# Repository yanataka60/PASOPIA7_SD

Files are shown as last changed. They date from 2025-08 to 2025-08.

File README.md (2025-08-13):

# TOSHIBA PASOPIA7、PASOPIAにSD-Cardとのロード、セーブ機能

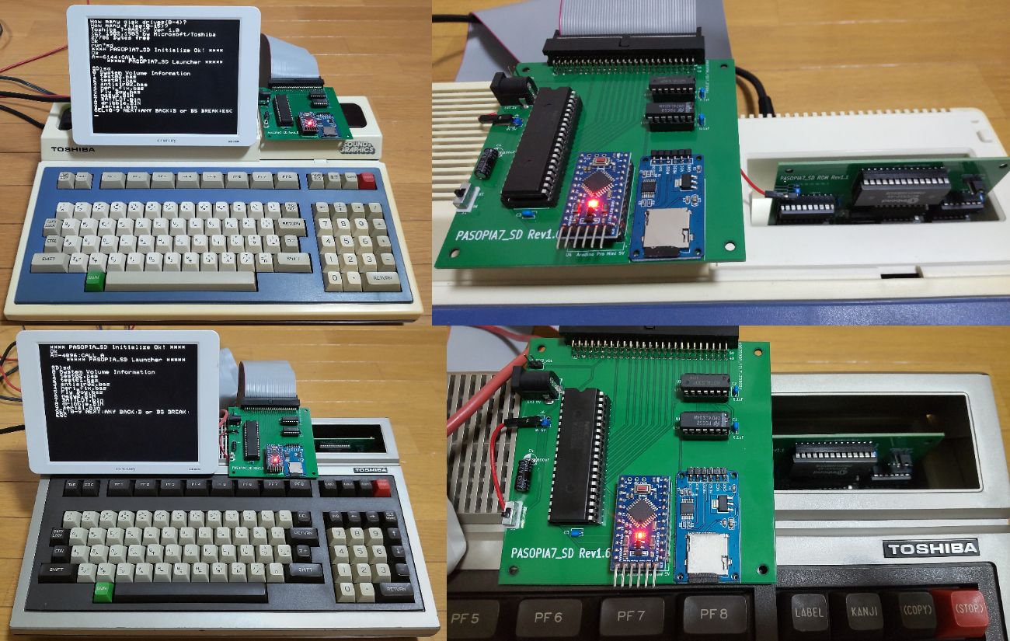
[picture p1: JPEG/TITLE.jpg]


　TOSHIBA PASOPIA7、PASOPIA(T-BASIC Ver1.1)でCMTの代わりにSD-CARDからロード、セーブを実現するものです。

　SDから読み込めるCMTのファイル形式はEMUで一般的なWAV、CASには対応していません。bugfire2009さんのDumpListEditorを使ってバイナリ形式に変換したものを使います。

　機械語 -> 各モデル固有ヘッダ付きBINファイル、拡張子は.bin

　BASIC -> BASファイル、拡張子は.bas

　CMTからの読み込み実行に数分掛かっていたゲームも数十秒で実行できます。

　ただし、CMT用プログラムのすべてがSD対応となるわけではありません。特に市販ゲームはCMT読み込みに独自ルーチンを使っているものもあるため、SD対応は不明です。

　なお、Arduino、ROMへ書き込むための機器が別途必要となります。

#### 　PASOPIAは、T-BASIC Ver1.1のみの対応です。また、OA-BASICも未対応です。

## 重要!!
　PASOPIA、PASOPIA7においてあるあるの電源ユニット部フィルムコンデンサの破裂ですが、修理に適切な品への交換されていない場合、電源電圧は正常(+5V)なのに信号電圧が異常(+10V程度)な状態となることがあるようです。

　私は当初電源電圧が正常であることを確認したものの原因が判らずArduino及びUSBシリアル変換モジュールを数個破壊してしまいました。

　当方ではCZRD信号の電圧が異常だったため、念のためPASOPIA7_SD基板にCZRD信号電圧を測るための「J6 TEST_VOL」端子を設けてあります。

　ICを装着する前に電圧をチェックし、+5V以上の電圧が出ているようであればまず電源ユニット部フィルムコンデンサを適切な品に交換してください。

　また、事前に調査するのであればPAC SLOT2 15Pin(CRD)の電圧を測ってみてください。

## 回路図(PASOPIA7、PASOPIA共通)
　PASOPIA7_SD本体基板とPASOPIA7_SD_ROM基板に分かれています。

　SDアクセスルーチンを読み込むためにPASOPIA7_SD_ROM基板(読込専用RAMPAC)を使用します。

　XPAC2又はRAMPACを持っていればそれにCMTから読み込んだSDアクセスルーチンを保存しておくことで使用することも可能です。詳細は後述の「XPAC2又はRAMPACの使用」を参照してください。

### PASOPIA7_SD本体基板
　KiCadフォルダ内のPASOPIA7_SD.PDFを参照してください。

[回路図](https://github.com/yanataka60/PASOPIA7_SD/blob/main/Kicad/1.6/PASOPIA7_SD.pdf)

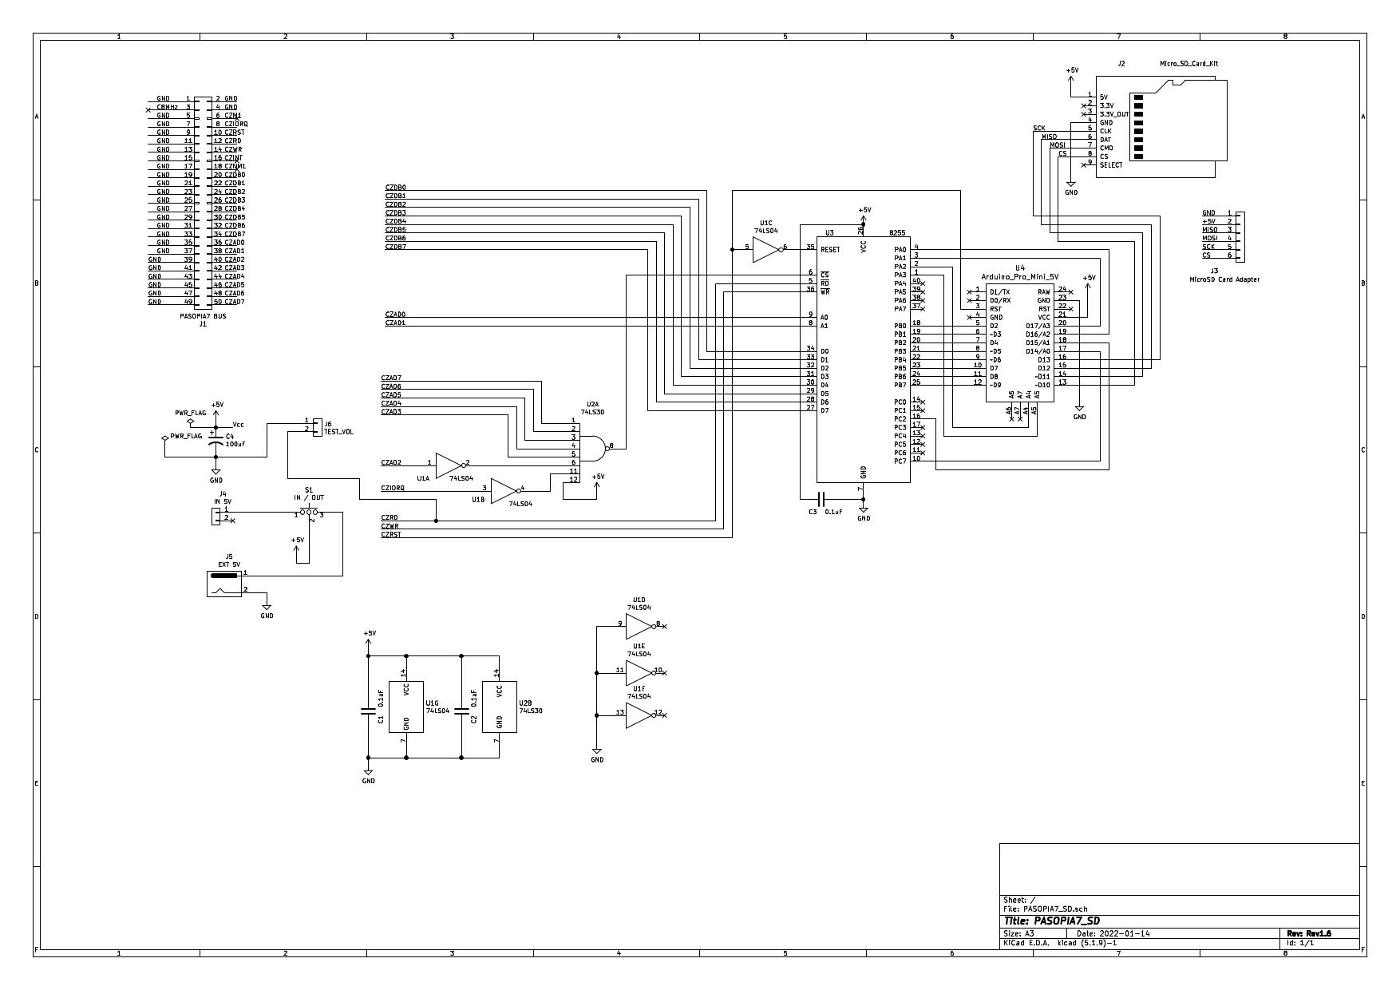
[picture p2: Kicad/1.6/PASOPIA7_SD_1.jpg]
PASOPIA7_SD


## 部品
|番号|品名|数量|備考|
| --- | --- | --- | --- |
|J1|2x25ボックスヘッダ|1|共立エレショップ JS-1200R-50など、秋月電子通商 PH-2x40RGなどのピンヘッダでも代用可(注4)|
||J2,J3のいずれか|||
|J2|Micro_SD_Card_Kit|1|秋月電子通商 AE-microSD-LLCNV (注1)|
|J3|MicroSD Card Adapter|1|Arduino等に使われる5V電源に対応したもの(注2)|
|U1|74LS04|1||
|U2|74LS30|1||
|U3|8255|1||
|U4|Arduino_Pro_Mini_5V|1|Atmega328版を使用 168版は不可。(注3)|
|C1-C3|積層セラミックコンデンサ 0.1uF|3||
|C4|電解コンデンサ 16v100uF|1||
|S1|3Pスライドスイッチ|1|秋月電子通商 SS12D01G4など|
|J4|コネクタ 2Pin|1|ピンヘッダで代用するときはGNDと間違えないよう1Pinで5Vだけにしたほうが良い|
|J5|DCジャック|1|秋月電子通商 MJ-179PHなど|
|J6|2P ピンヘッダ|1|秋月電子通商 PH-1x40SGなど|
||2.54mmピッチ2x25Pinフラットケーブル|1||
||PASOPIA7_SDとPASOPIA7_SD_ROMを繋ぐケーブル|15cm～30cm|ジャンプワイヤー メス-メスなど|

PASOPIA7_SDに外部から電源を供給する場合
|番号|品名|数量|備考|
| --- | --- | --- | --- |
||ACアダプター 5V|1|秋月電子通商 M050200-A010JPなど|

### 注1)秋月電子通商　AE-microSD-LLCNVのJ1ジャンパはショートしてください。

### 注2)MicroSD Card Adapterを使う場合

J3に取り付けます。

MicroSD Card Adapterについているピンヘッダを除去してハンダ付けするのが一番確実ですが、J2の穴にMicroSD Card Adapterをぴったりと押しつけ、裏から多めにハンダを流し込むことでハンダ付けをする方法もあります。なお、この方法の時にはしっかりハンダ付けが出来たかテスターで導通を確認しておいた方が安心です。

ハンダ付けに自信のない方はJ1の秋月電子通商　AE-microSD-LLCNVをお使いください。AE-microSD-LLCNVならパワーLED、アクセスLEDが付いています。

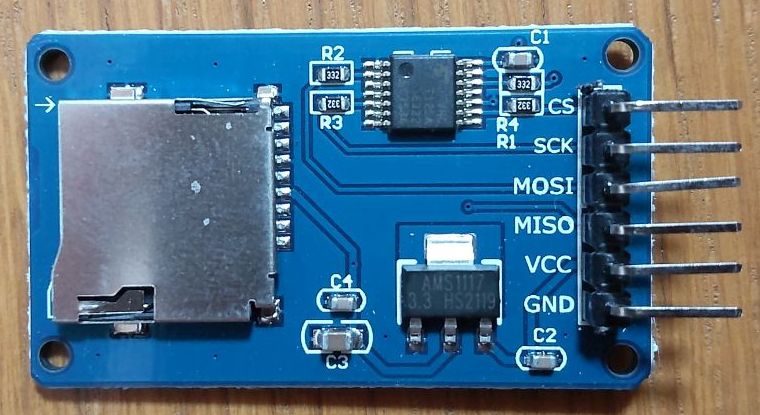
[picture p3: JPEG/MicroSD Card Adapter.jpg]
MicroSD Card Adapter1


### 注3)Arduino Pro MiniはA4、A5ピンも使っています。

#### 注4)ピンヘッダで代用するときは、基板から若干浮かせてピンヘッダをハンダ付けするとフラットケーブルをスムーズに抜き差しできます。

### PASOPIA7_SD_ROM基板
　KiCadフォルダ内のPASOPIA7_SD.PDFを参照してください。

[回路図](https://github.com/yanataka60/PASOPIA7_SD/blob/main/Kicad/ROM/PASOPIA7_SD_ROM.pdf)

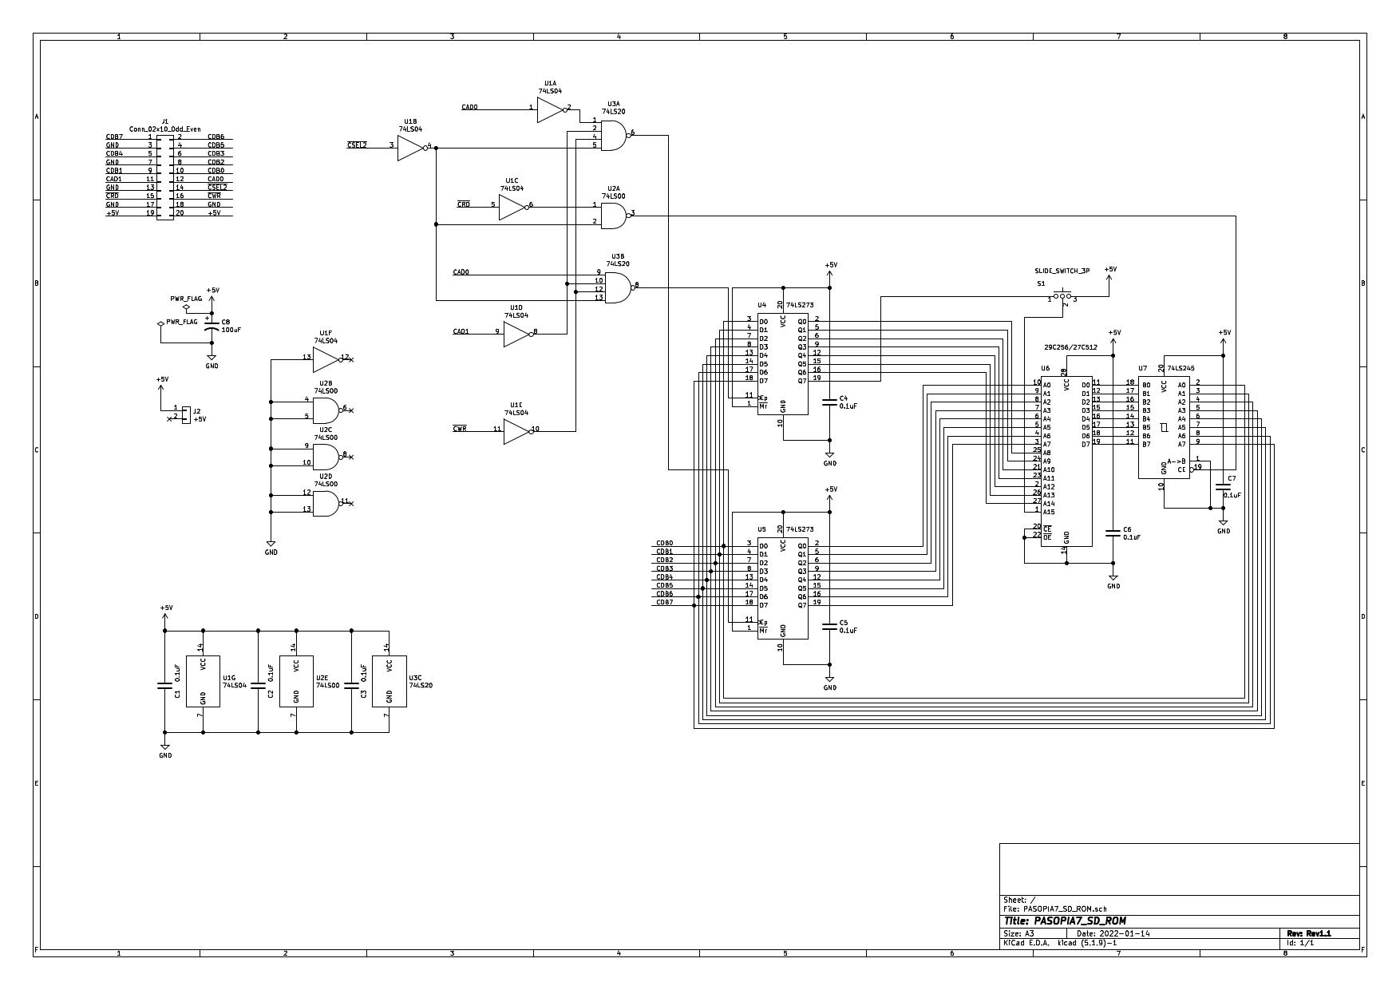
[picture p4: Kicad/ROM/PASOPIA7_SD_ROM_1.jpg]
PASOPIA7_SD

|番号|品名|数量|備考|
| --- | --- | --- | --- |
|U1|74LS04|1||
|U2|74LS00|1||
|U3|74LS20|1||
|U4-U5|74LS273|2||
|U6|ROM 27256/29C256又は27512/27C512相当品|1|入手しやすいものでOK、28C256は不可|
|U7|74LS245|1||
|C1-C7|積層セラミックコンデンサ 0.1uF|7||
|C8|電解コンデンサ 16v100uF|1||
|S1|3Pin ピンヘッダーとジャンパーピン又は3Pスライドスイッチ|1|秋月電子通商 SS12D01G4など|
|J2|コネクタ 2Pin|1|ピンヘッダで代用するときはGNDと間違えないよう1Pinで5Vだけにしたほうが良い|

## 取り付け(PASOPIA7、PASOPIA共通)
　PASOPIA7_SD本体基板はPASOPIA7(PASOPIA)本体後部の拡張端子とフラットケーブルで接続します。50Pinフラットケーブルは、コネクタのボッチとケーブルの返しが両方上になる側のコネクタを本体に嵌めます。

　ケーブルの返しを下にして本体に嵌めると一見嵌っているように見えても接触不良を起こしていることがあります。

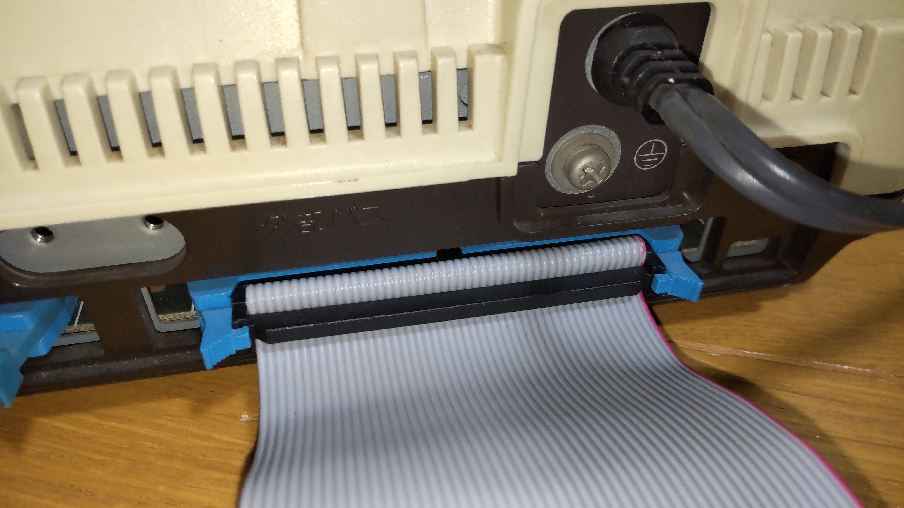
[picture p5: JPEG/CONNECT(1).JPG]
Connect1


　PASOPIA7_SD_ROM基板はPACスロット2に挿入します。この時PASOPIA7_SD_ROM基板は部品実装面を手前にして挿入してください。基板の右端をスロットの右に合わせるように挿入すればズレずに挿入できると思います。

　次にPASOPIA7_SD_ROM基板への+5V供給のため、PASOPIA7_SD_ROM基板の+5V端子(J2)とPASOPIA7_SD本体基板の+5V端子(J4)を繋いでください。

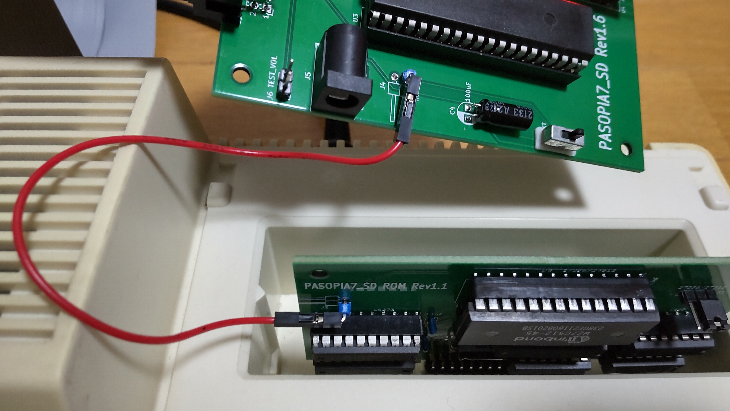
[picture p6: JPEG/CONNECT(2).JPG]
Connect2


　XPAC2又はRAMPACを使用するときは、外部電源として5V電源アダプタを接続するか、内部電源としてPAC SLOT1の43Pin又は44Pinから+5Vを取り出してジャンプワイヤー オス-メスなどで接続します。

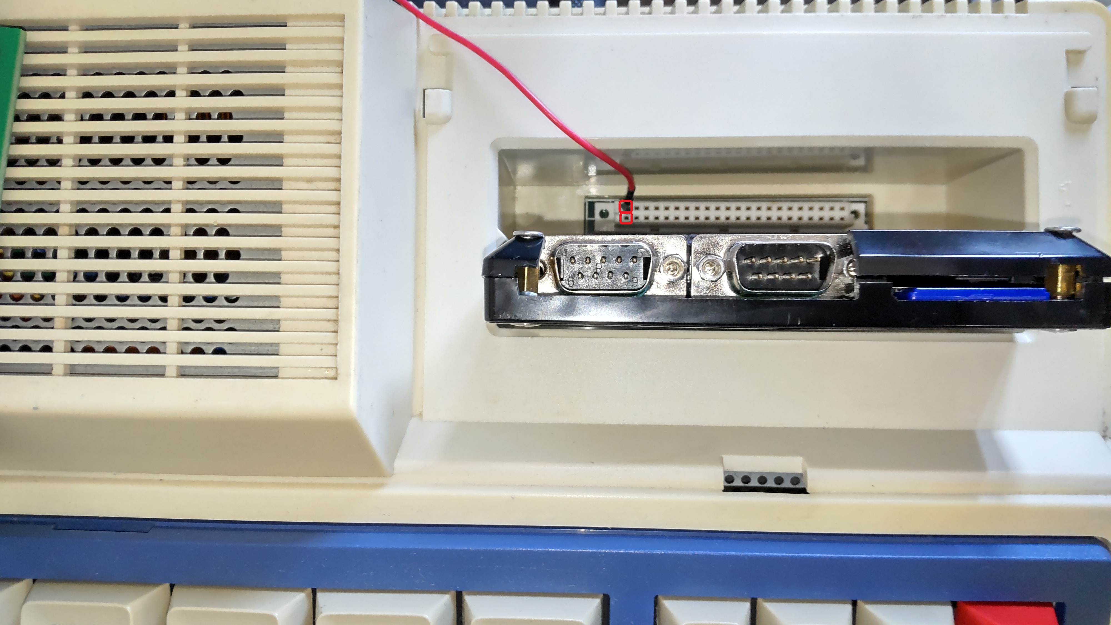
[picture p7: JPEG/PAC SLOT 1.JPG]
Connect3


## ROMへの書込み(PASOPIA7、PASOPIA共通)
　Z80フォルダ内のRAMPAC.binをROMライター(TL866II Plus等)を使って27256又は27512に書き込みます。

　実際に使用しているのは32KByte分(32Kx8)です。

　PASOPIA7_SD_ROM基板のROMはPASOPIA7(PASOPIA)からはRAMPACとして扱われます。(PASOPIA7(PASOPIA)から書き込みはできません。)

## RAMPAC.binに登録されているファイル
　RAMPAC.binに登録されているファイルは次の2つになります。

|ファイル名|種類|備考|
| --- | --- | --- |
|sd|BASIC|PASOPIA7用|
|SDBOOT|BINARY|PASOPIA7用|
|sdt|BASIC|PASOPIA用|
|SDTBOOT|BINARY|PASOPIA用|

　また、RAMPAC.binへのファイル登録はTAKEDAさんのEMU ePASOPIA7で行っており、RAMPAC1としてファイルを選択すればePASOPIA7から読み書き出来ます。

## XPAC2又はRAMPACの使用(PASOPIA7、PASOPIA共通)
　XPAC2又はRAMPACを持っていればPASOPIA7_SD_ROM基板の代わりに使用できます。

　ただし、PASOPIA7_SD本体基板への+5V供給を独自に用意する必要があります。内部から引き出すか、5V電源アダプタを用意するかですが、PACスロット1 44Pinから取るのが簡単だと思います。

### XPAC2
　ePASOPIA7で扱うRAMPACKが32KByteなのに対してXPAC2で扱うSLOT4は64KByteです。

　XPAC2のSD-CARDへRAMPAC.binをコピーしてXPAC2 SLOT4へ登録することも可能とは思われますが、容量が32KByteとなってしまう気がします。

　XPAC2 SLOT4を64KByteのまま使いたいのであればsd.wav(sdt.wav)、SDBOOT.wav(SDTBOOT.wav)をCMTインタフェースから読み込み、XPAC2 SLOT4へ保存してください。

### RAMPAC
　RAMPAC.binをRAMPACへ登録する方法がありませんのでsd.wav(sdt.wav)、SDBOOT.wav(SDTBOOT.wav)をCMTインタフェースから読み込み、RAMPACへ保存してください。

## Arduinoプログラム(PASOPIA7、PASOPIA共通)
　Arduino IDEを使ってArduinoフォルダのPASOPIA7_SDフォルダ内PASOPIA7_SD.inoを書き込みます。

　SdFatライブラリを使用しているのでArduino IDEメニューのライブラリの管理からライブラリマネージャを立ち上げて「SdFat」をインストールしてください。

　「SdFat」で検索すれば見つかります。「SdFat」と「SdFat - Adafruit Fork」が見つかりますが「SdFat」のほうを使っています。

注)Arduinoを基板に直付けしている場合、Arduinoプログラムを書き込むときは、PASOPIA7(PASOPIA)本体とは接続を外し、U1 74LS04を外したうえで書き込んでください。

## SD-CARD(PASOPIA7、PASOPIA共通)
　出来れば8GB以下のSDカードを用意してください。

　ArduinoのSdFatライブラリは、SD規格(最大2GB)、SDHC規格(2GB～32GB)に対応していますが、SDXC規格(32GB～2TB)には対応していません。

　また、SDHC規格のSDカードであっても32GB、16GBは相性により動作しないものがあるようです。

　FAT16又はFAT32が認識できます。NTFSは認識できません。

## 操作方法
### PASOPIA7
　起動直後に「RUN"sd"」を実行してSDアクセスルーチンの読込、初期化の実行を行います。

　SDアクセスルーチンはE800h～EFCFhに読み込まれます。

　SDアクセスメニューを表示するにはA=&HE800:CALL Aを実行しますが、PF6ファンクションキーに登録してありますのでPF6ファンクションキーを押しても大丈夫です。

### PASOPIA(T-BASIC Ver1.1のみ対応)
　起動直後に「RUN"sdt"」を実行してSDアクセスルーチンの読込、初期化の実行を行います。

　SDアクセスルーチンはF000h～F776hに読み込まれます。

　SDアクセスメニューを表示するにはA=&HF000:CALL Aを実行しますが、PF6ファンクションキーに登録してありますのでPF6ファンクションキーを押しても大丈夫です。

#### 扱えるファイル(PASOPIA7、PASOPIA共通)
bugfire2009さんのDumpListEditorを使ってバイナリ形式に変換したものを使います。

扱う機種をPASOPIA7に変更したうえで変換します。

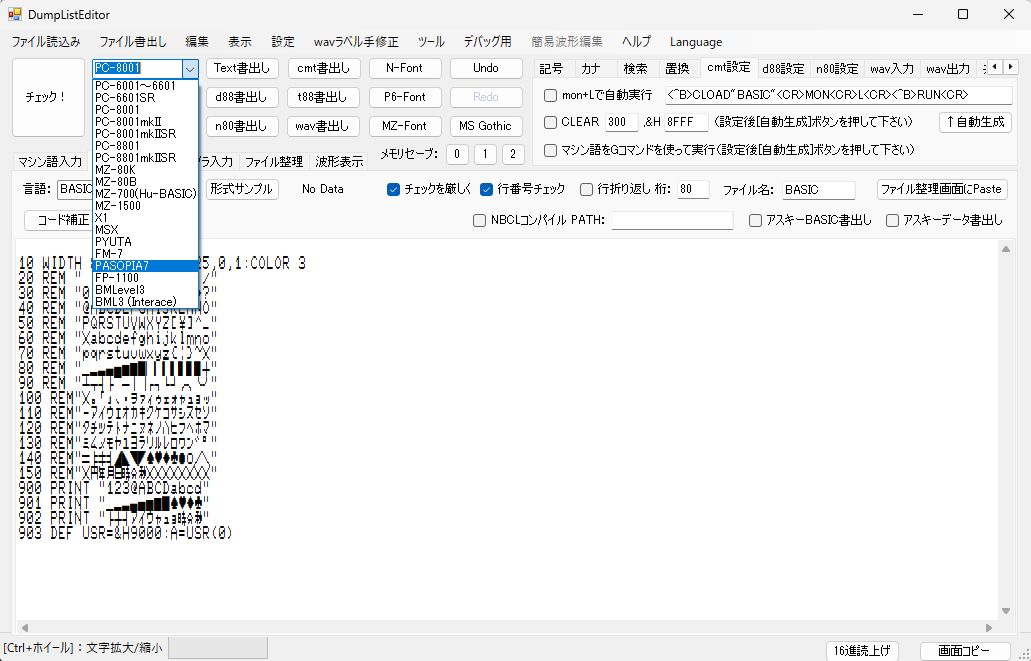
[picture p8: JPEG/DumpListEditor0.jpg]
DumpListEditor0


##### 機械語 -> 「BINファイル書出し(各モデル固有ヘッダ付き)」で保存、拡張子は.bin

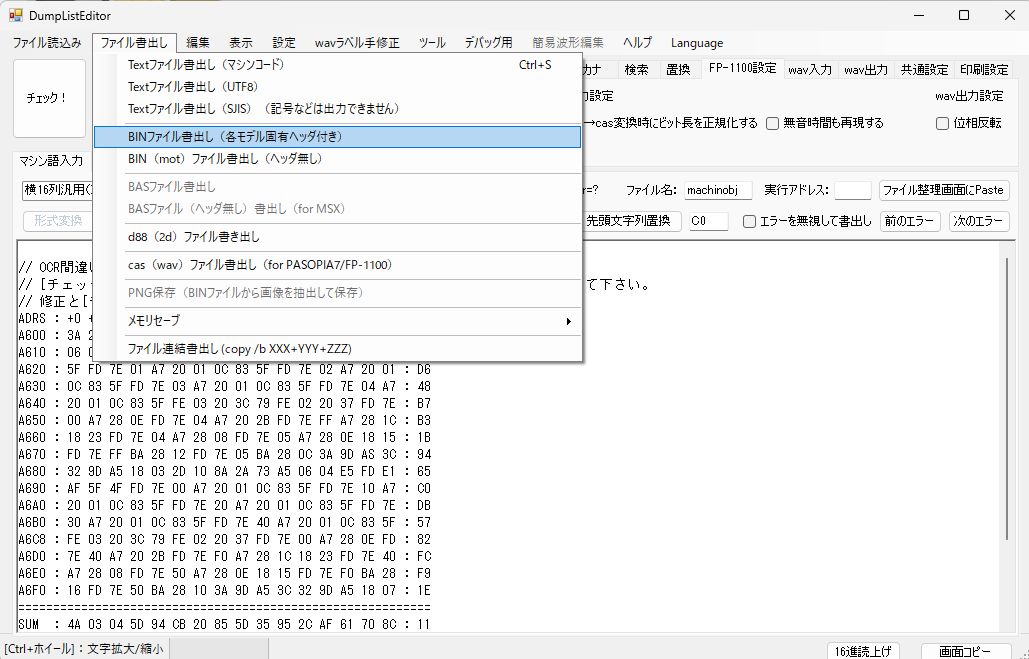
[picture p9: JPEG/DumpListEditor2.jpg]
DumpListEditor1


##### BASIC -> 「BASファイル書出し」で保存、拡張子は.bas

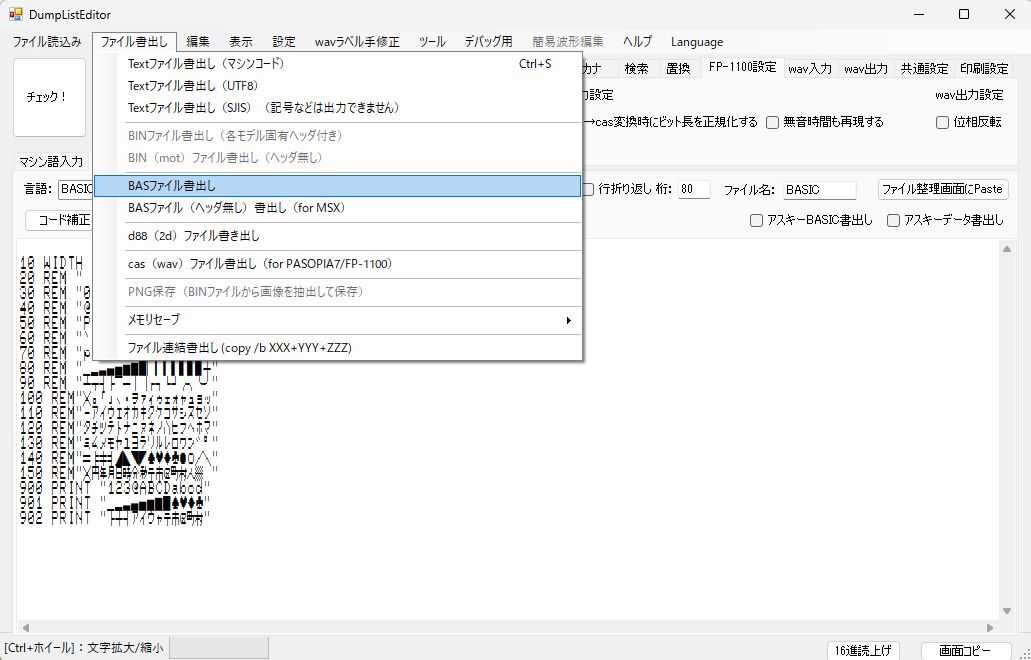
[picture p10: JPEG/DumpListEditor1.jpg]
DumpListEditor2


### コマンド(PASOPIA7、PASOPIA共通)
　コマンド入力時にBSキー又は左カーソルキーで直前に入力した文字を訂正できます。

　CLR、HOME、上・下・右カーソルキーは画面が乱れるだけで入力文字の訂正は出来ません。

#### SD[RETURN]又はSD 文字列[RETURN]
　文字列を入力せずにSD[RETURN]のみ入力するとSD-CARDルートディレクトリにあるファイルの一覧を表示します。

　文字列を付けて入力すればSD-CARDルートディレクトリにあるその文字列から始まるファイルの一覧を表示します。
　10件表示したところで指示待ちになるのでESCキーで終了、Bキー又はBSキーで前の10件に戻ります。それ以外のキーで次の10件を表示します。

　表示される順番は、登録順となりファイル名アルファベッド順などのソートした順で表示することはできません。

　LOADしたいファイルを見つけたら左端の数字のキーを押せばLOADされます。

　BASICプログラムか、機械語プログラムかは自動で判断します。

　なお、PASOPIA7はE7FFh以降、PASOPIAはEFFFH以降へ機械語プログラムがLOADされた場合、次の五段階の挙動となります。

||PASOPIA7|PASOPIA|挙動|
|---- | --- | --- | --- |
|1|～E8FCh|～F0FAh|機械語プログラムをLOAD後は、SM,SBコマンドが使用できなくなります。LM,LG,LB,SD,J,Q,Bコマンドは使用できます。|
|2|～EC54h|～F423h|機械語プログラムをLOAD後は、J,Q,Bのみ使えます。SD,LMコマンドでLOADした後、Jコマンドでの実行は可能です。|
|3|～EDC6h|～F582h|BASICプログラムLOADの限界です。通常はCLEAR文で設定したメインメモリの上限E800hですが、F000hに変更すればEDC6hまでのBASICプログラムを一度だけLOAD出来ます。|
|4|～EE61h|～F614h|BASIC中からはこれ以降への機械語LOADは出来ません。|
|5|～EEE7h|～F691h|機械語プログラムをLOAD後は、すべてのコマンドが使えません。EDC7h以降までLOADされた場合は強制的に実行番地にジャンプを試みます。|

##### 例)
　　SD[RETURN]

　　SD S[RETURN]

　　SD SP[RETURN]

#### LM DOSファイル名[RETURN]
　指定したDOSフィル名の機械語プログラムをSD-CARDからLOADします。

　拡張子が「bin」であるファイルだけが対象でファイル名の最後が「.BIN」でない場合には自動的に付加されます。

　なお、PASOPIA7はE7FFh以降、PASOPIAはEFFFH以降へ機械語プログラムがLOADされた場合、次の五段階の挙動となります。

||PASOPIA7|PASOPIA|挙動|
|---- | --- | --- | --- |
|1|～E8FCh|～F0FAh|機械語プログラムをLOAD後は、SM,SBコマンドが使用できなくなります。LM,LG,LB,SD,J,Q,Bコマンドは使用できます。|
|2|～EC54h|～F423h|機械語プログラムをLOAD後は、J,Q,Bのみ使えます。SD,LMコマンドでLOADした後、Jコマンドでの実行は可能です。|
|3|～EDC6h|～F582h|BASICプログラムLOADの限界です。通常はCLEAR文で設定したメインメモリの上限E800hですが、F000hに変更すればEDC6hまでのBASICプログラムを一度だけLOAD出来ます。|
|4|～EE61h|～F614h|BASIC中からはこれ以降への機械語LOADは出来ません。|
|5|～EEE7h|～F691h|機械語プログラムをLOAD後は、すべてのコマンドが使えません。EDC7h以降までLOADされた場合は強制的に実行番地にジャンプを試みます。|

##### 例)
　　LM TEST[RETURN] -> DOSファイル名「TEST.BIN」を読み込みます。

　　LM TEST.BIN[RETURN] -> DOSファイル名「TEST.BIN」を読み込みます。

　　LM TEST.BAS[RETURN] -> DOSファイル名「TEST.BAS.BIN」を読み込みます。

#### LG DOSファイル名[RETURN]
　指定したDOSフィル名の機械語プログラムをSD-CARDからLOADした後、実行開始アドレスへジャンプします。

　LOAD後そのまま実行するのでFF64hまでLOADしても大丈夫です。

　LOADした後、実行開始アドレスへジャンプする以外はLMコマンドと同じです。

#### LB DOSファイル名[RETURN]
　現在選択しているPROGエリアに指定したDOSフィル名のBASICプログラムをSD-CARDからLOADします。

　LOADするPROGエリアを切り替えたい場合にはSDメニューに入る前に切り替えておいてください。

　拡張子が「BAS」であるファイルだけが対象でファイル名の最後が「.BAS」でない場合には自動的に付加されます。

##### 例)
　　LB TEST[RETURN] -> DOSファイル名「TEST.BAS」を読み込みます。

　　LB TEST.BAS[RETURN] -> DOSファイル名「TEST.BAS」を読み込みます。

　　LB TEST.BIN[RETURN] -> DOSファイル名「TEST.BIN.BAS」を読み込みます。

#### SM XXXX,YYYY,DOSファイル名[RETURN]　(XXXX,YYYYは16進数4桁を表す文字列)
　XXXX番地からYYYY番地までの機械語プログラムを指定したDOSフィル名でSD-CARDにSAVEします。

　拡張子の指定「.BIN」は省略することが出来、ファイル名の最後が「.BIN」でない場合には自動的に付加されます。

##### 例)
　　SM B000,BFFF,TEST[RETURN] -> B000h～BFFFhまでをDOSファイル名「TEST.BIN」でSAVEします。

　　SM B000,BFFF,TEST.BIN[RETURN] -> B000h～BFFFhまでをDOSファイル名「TEST.BIN」でSAVEします。

　　SM B000,BFFF,TEST.BAS[RETURN] -> B000h～BFFFhまでをDOSファイル名「TEST.BAS.BIN」でSAVEします。

#### SB DOSファイル名[RETURN]
　現在選択しているPROGエリアのBASICプログラムを指定したDOSフィル名でSD-CARDにSAVEします。

　SAVEするPROGエリアを切り替えたい場合にはSDメニューに入る前に切り替えておいてください。

　拡張子の指定「.BAS」は省略することが出来、ファイル名の最後が「.BAS」でない場合には自動的に付加されます。

##### 例)
　　SB TEST[RETURN] -> DOSファイル名「TEST.BAS」でSAVEします。

　　SB TEST.BAS[RETURN] -> DOSファイル名「TEST.BAS」でSAVEします。

　　SB TEST.BIN[RETURN] -> DOSファイル名「TEST.BIN.BAS」でSAVEします。

#### J[RETURN]又はJ 16進数4桁[RETURN]
　Jだけの場合は、直前にLOADした機械語プログラムの先頭番地へジャンプします。

　16進数4桁を指定した場合は16進数4桁が表すアドレスにジャンプします。

　Jの後ろに空白があっても無くても構いません。

#### B[RETURN]又はQ[RETURN]
　BASICに復帰します。

### BASICプログラム中から機械語プログラムをLOADする
#### PASOPIA7
　BASICプログラム中に「CALL &HE803:REM ファイル名」と記述することで機械語プログラムをLOAD出来ます。

　ファイル名はSDカードに保存されている拡張子も含めたファイル名を記述します。

　通常LOAD可能なのはCLEAR文で設定したメインメモリの上限E7FFhですが、F000hに変更すればEE61hまでのBASICプログラムをLOAD出来ます。

##### 例)

20 B=&HE803:CALL B:REM antiair.bin

#### PASOPIA(T-BASIC Ver1.1)
　BASICプログラム中に「CALL &HF003:REM ファイル名」と記述することで機械語プログラムをLOAD出来ます。

　ファイル名はSDカードに保存されている拡張子も含めたファイル名を記述します。

　通常LOAD可能なのはCLEAR文で設定したメインメモリの上限EFFFhですが、F7FChに変更すればF614hまでのBASICプログラムをLOAD出来ます。

##### 例)

20 B=&HE803:CALL B:REM antiair.bin

## 未解決事項(2025.8.11)
　PASOPIA7_SDからPASOPIA、PASOPIA7の両機種でいぬふと様のゲームを起動したとき、以下の症状が出ることがあります。

#### 　原因を調査中ですが特定に至っていません。しかし、CMTからの起動においては症状はでませんのでいぬふと様のゲームに問題があるのではなく、PASOPIA7_SD側の問題と思われますのでこの件に関していぬふと様に問い合わせることはご遠慮くださるようお願いします。

### PASOPIA
　表示がずれます。ゲーム起動直前にwidth 40を実行すると回避できるようです。

　PASOPIA7_SD起動時にwidth 40:width 36としていますが、それでも表示がずれる場合にはゲーム起動直前にwidth 40を実行してから起動してみてください。

### PASOPIA7
　いくつかのゲームで何も押していないのに勝手にキー入力され続けてしまうことがあります。また症状が出るときと出ない時があり、原因の特定に至っていません。

　症状が出ない時には普通にゲームができます。今のところ、回避方法、対策が見つかっていません。

## 操作上の注意
　電源を入れたままSD-CARDの抜き差しをする場合又は「SD-CARD INITIALIZE ERROR」と表示されたときは、SD-CARDを挿入後、SD、LM、LBコマンド等でSD-CARDに3回ほどアクセスすれば復旧します。

　SD-CARDの抜き差しは電源を切った状態で行うほうがより確実です。

## 謝辞
　基板の作成に当たり以下のデータを使わせていただきました。ありがとうございました。

　Arduino Pro Mini

　　https://github.com/g200kg/kicad-lib-arduino

　AE-microSD-LLCNV

　　https://github.com/kuninet/PC-8001-SD-8kRAM

## 追記
2025.8.14 PASOPIAはT-BASIC Ver1.1のみ対応していることを追記。BASICプログラム中から機械語プログラムをLOADするときのファイル名には拡張子も含めることを追記。

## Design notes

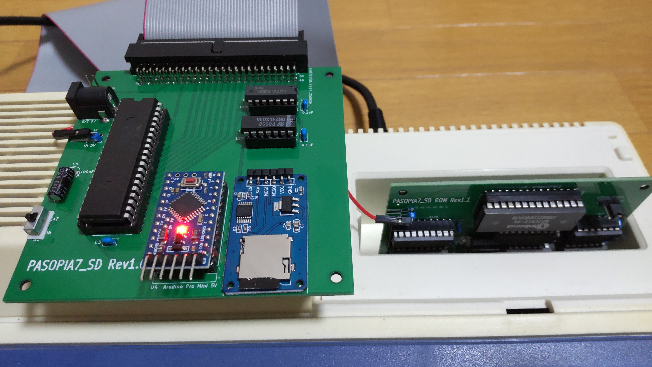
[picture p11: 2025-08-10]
JPEG/PASOPIA7_SD(2).jpg

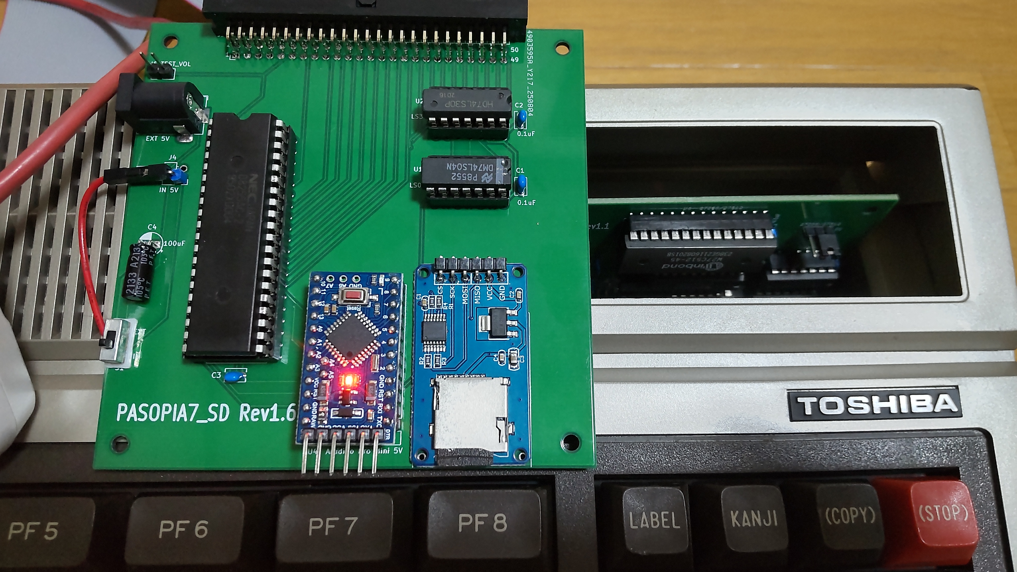
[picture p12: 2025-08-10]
JPEG/PASOPIA(2).jpg

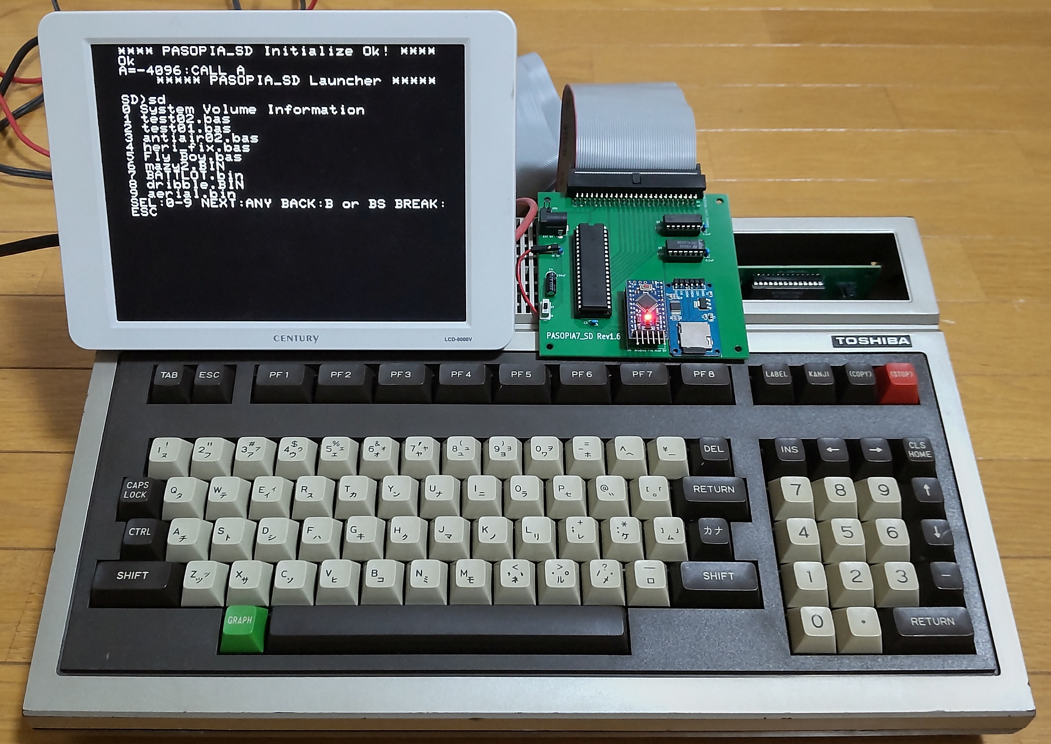
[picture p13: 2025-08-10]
JPEG/PASOPIA(1).jpg

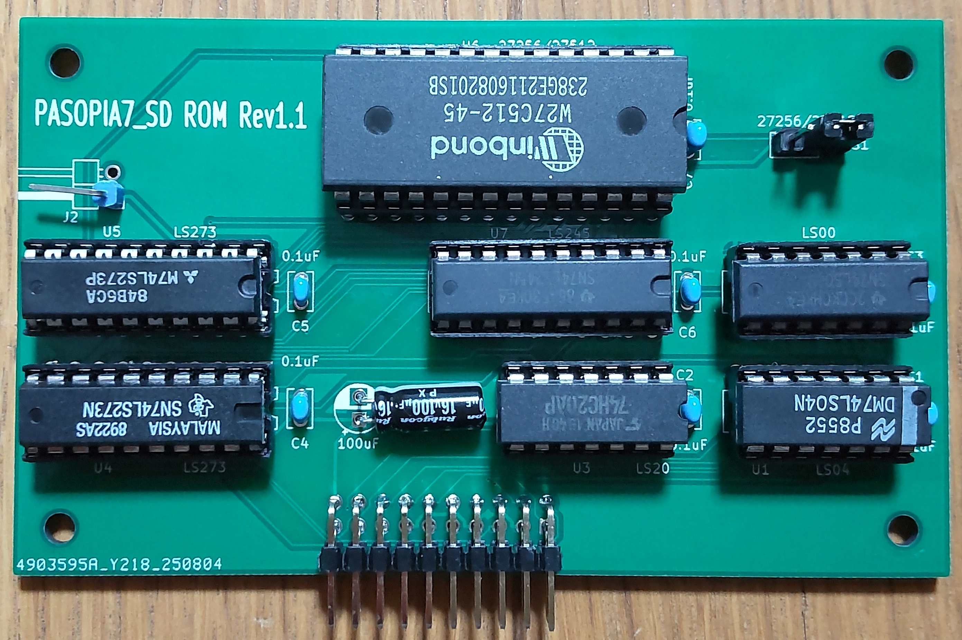
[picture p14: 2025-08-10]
JPEG/PASOPIA7_SD(5).jpg

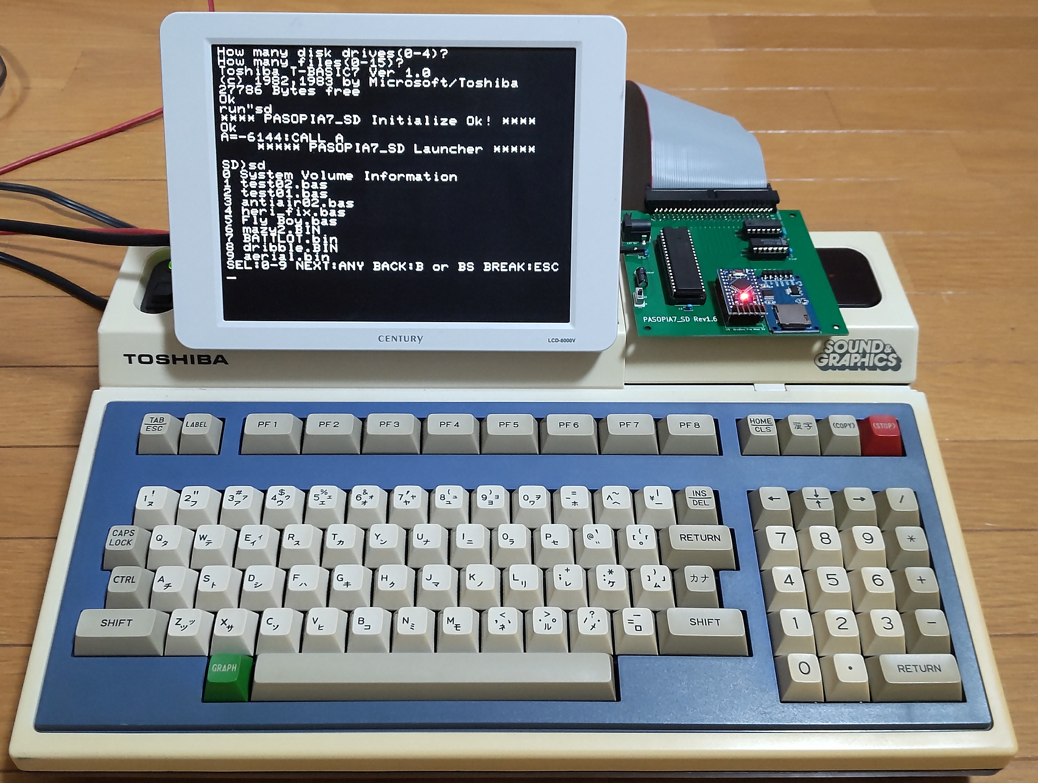
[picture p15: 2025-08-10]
JPEG/PASOPIA7_SD(1).jpg

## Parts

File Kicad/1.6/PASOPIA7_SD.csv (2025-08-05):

Reference | Value | Footprint | Datasheet
J1 | PASOPIA7 BUS | Connector_PinHeader_2.54mm:PinHeader_2x25_P2.54mm_Horizontal | ~
C1 | 100uF | Capacitor_THT:CP_Radial_D5.0mm_P2.50mm | ~
U2 | 74LS30 | Package_DIP:DIP-14_W7.62mm_LongPads | http://www.ti.com/lit/gpn/sn74LS30
U1 | 74LS04 | Package_DIP:DIP-14_W7.62mm_LongPads | http://www.ti.com/lit/gpn/sn74LS04
C2 | 0.1uF | Capacitor_THT:C_Rect_L4.0mm_W2.5mm_P2.50mm | ~
C3 | 0.1uF | Capacitor_THT:C_Rect_L4.0mm_W2.5mm_P2.50mm | ~
J2 | Micro_SD_Card_Kit | Kicad:AE-microSD-LLCNV | http://katalog.we-online.de/em/datasheet/693072010801.pdf
C4 | 0.1uF | Capacitor_THT:C_Rect_L4.0mm_W2.5mm_P2.50mm | ~
U3 | 8255 | Package_DIP:DIP-40_W15.24mm_LongPads | http://aturing.umcs.maine.edu/~meadow/courses/cos335/Intel8255A.pdf
U4 | Arduino_Pro_Mini_5V | Kicad:Arduino_Pro_Mini | https://www.sparkfun.com/products/11113
J3 | MicroSD Card Adapter | Connector_PinSocket_2.54mm:PinSocket_1x06_P2.54mm_Vertical | ~
U13 | 74LS245 | Package_DIP:DIP-20_W7.62mm_LongPads | http://www.ti.com/lit/gpn/sn74LS245
C12 | 0.1uF | Capacitor_THT:C_Rect_L4.0mm_W2.5mm_P2.50mm | ~
C13 | 0.1uF | Capacitor_THT:C_Rect_L4.0mm_W2.5mm_P2.50mm | ~
U6 | 74LS04 | Package_DIP:DIP-14_W7.62mm_LongPads | http://www.ti.com/lit/gpn/sn74LS04
U7 | 74LS10 | Package_DIP:DIP-14_W7.62mm_LongPads | http://www.ti.com/lit/gpn/sn74LS10
U5 | 74LS30 | Package_DIP:DIP-14_W7.62mm_LongPads | http://www.ti.com/lit/gpn/sn74LS30
U9 | 74LS193 | Package_DIP:DIP-16_W7.62mm_LongPads | http://www.ti.com/lit/ds/symlink/sn74ls193.pdf
U10 | 74LS193 | Package_DIP:DIP-16_W7.62mm_LongPads | http://www.ti.com/lit/ds/symlink/sn74ls193.pdf
U11 | 74LS193 | Package_DIP:DIP-16_W7.62mm_LongPads | http://www.ti.com/lit/ds/symlink/sn74ls193.pdf
U8 | 74LS14 | Package_DIP:DIP-14_W7.62mm_LongPads | http://www.ti.com/lit/gpn/sn74LS14
R1 | 100 | Resistor_THT:R_Axial_DIN0207_L6.3mm_D2.5mm_P7.62mm_Horizontal | ~
C14 | 220pF | Capacitor_THT:C_Rect_L4.0mm_W2.5mm_P2.50mm | ~
C9 | 0.1uF | Capacitor_THT:C_Rect_L4.0mm_W2.5mm_P2.50mm | ~
C10 | 0.1uF | Capacitor_THT:C_Rect_L4.0mm_W2.5mm_P2.50mm | ~
C11 | 0.1uF | Capacitor_THT:C_Rect_L4.0mm_W2.5mm_P2.50mm | ~
C5 | 0.1uF | Capacitor_THT:C_Rect_L4.0mm_W2.5mm_P2.50mm | ~
C6 | 0.1uF | Capacitor_THT:C_Rect_L4.0mm_W2.5mm_P2.50mm | ~
C7 | 0.1uF | Capacitor_THT:C_Rect_L4.0mm_W2.5mm_P2.50mm | ~
C8 | 0.1uF | Capacitor_THT:C_Rect_L4.0mm_W2.5mm_P2.50mm | ~
U12 | 2764 | Package_DIP:DIP-28_W15.24mm_LongPads | https://downloads.reactivemicro.com/Electronics/ROM/2764%20EPROM.pdf
J4 | IN 5V | Connector_PinHeader_2.54mm:PinHeader_1x02_P2.54mm_Horizontal | ~
S1 | IN / OUT | Connector_PinHeader_2.54mm:PinHeader_1x03_P2.54mm_Vertical
J5 | EXT 5V | Connector_BarrelJack:BarrelJack_Horizontal | ~

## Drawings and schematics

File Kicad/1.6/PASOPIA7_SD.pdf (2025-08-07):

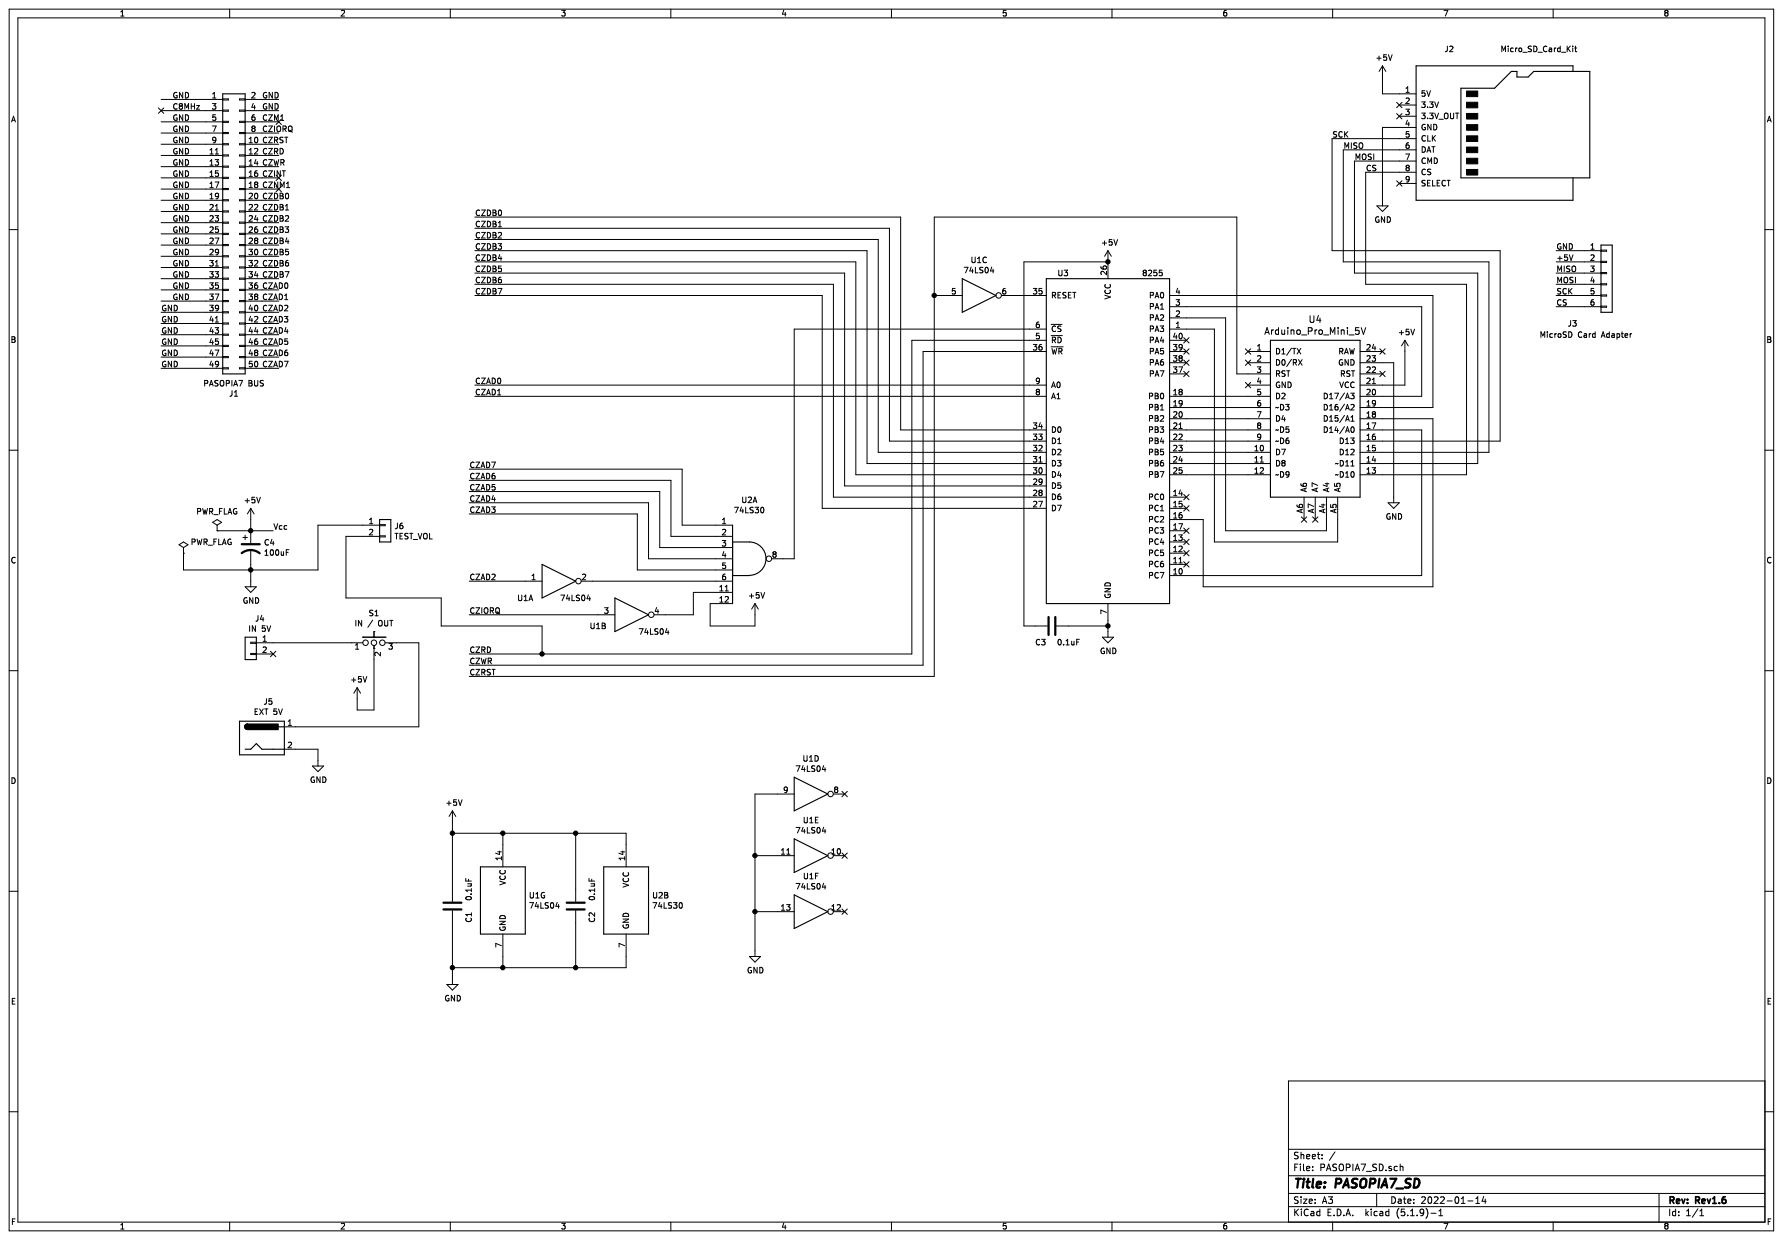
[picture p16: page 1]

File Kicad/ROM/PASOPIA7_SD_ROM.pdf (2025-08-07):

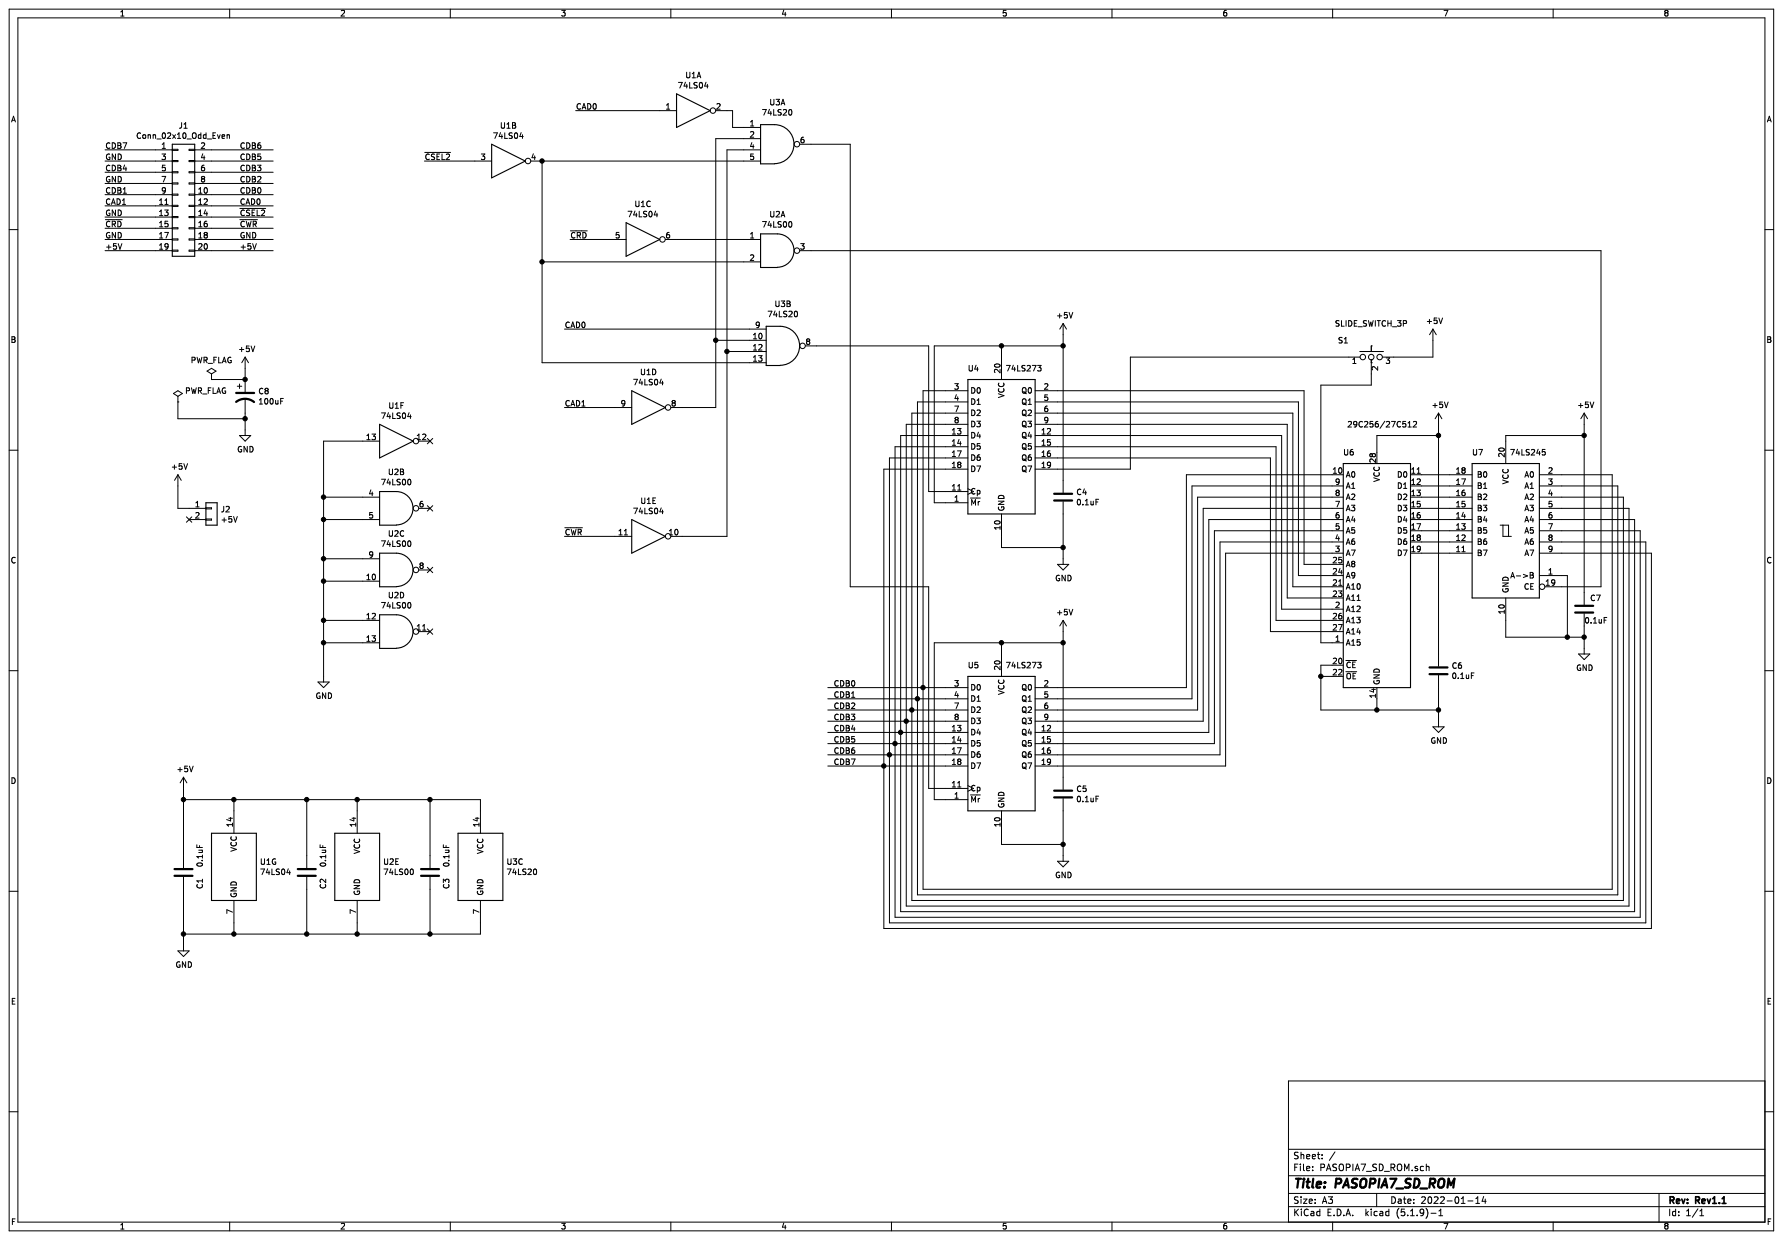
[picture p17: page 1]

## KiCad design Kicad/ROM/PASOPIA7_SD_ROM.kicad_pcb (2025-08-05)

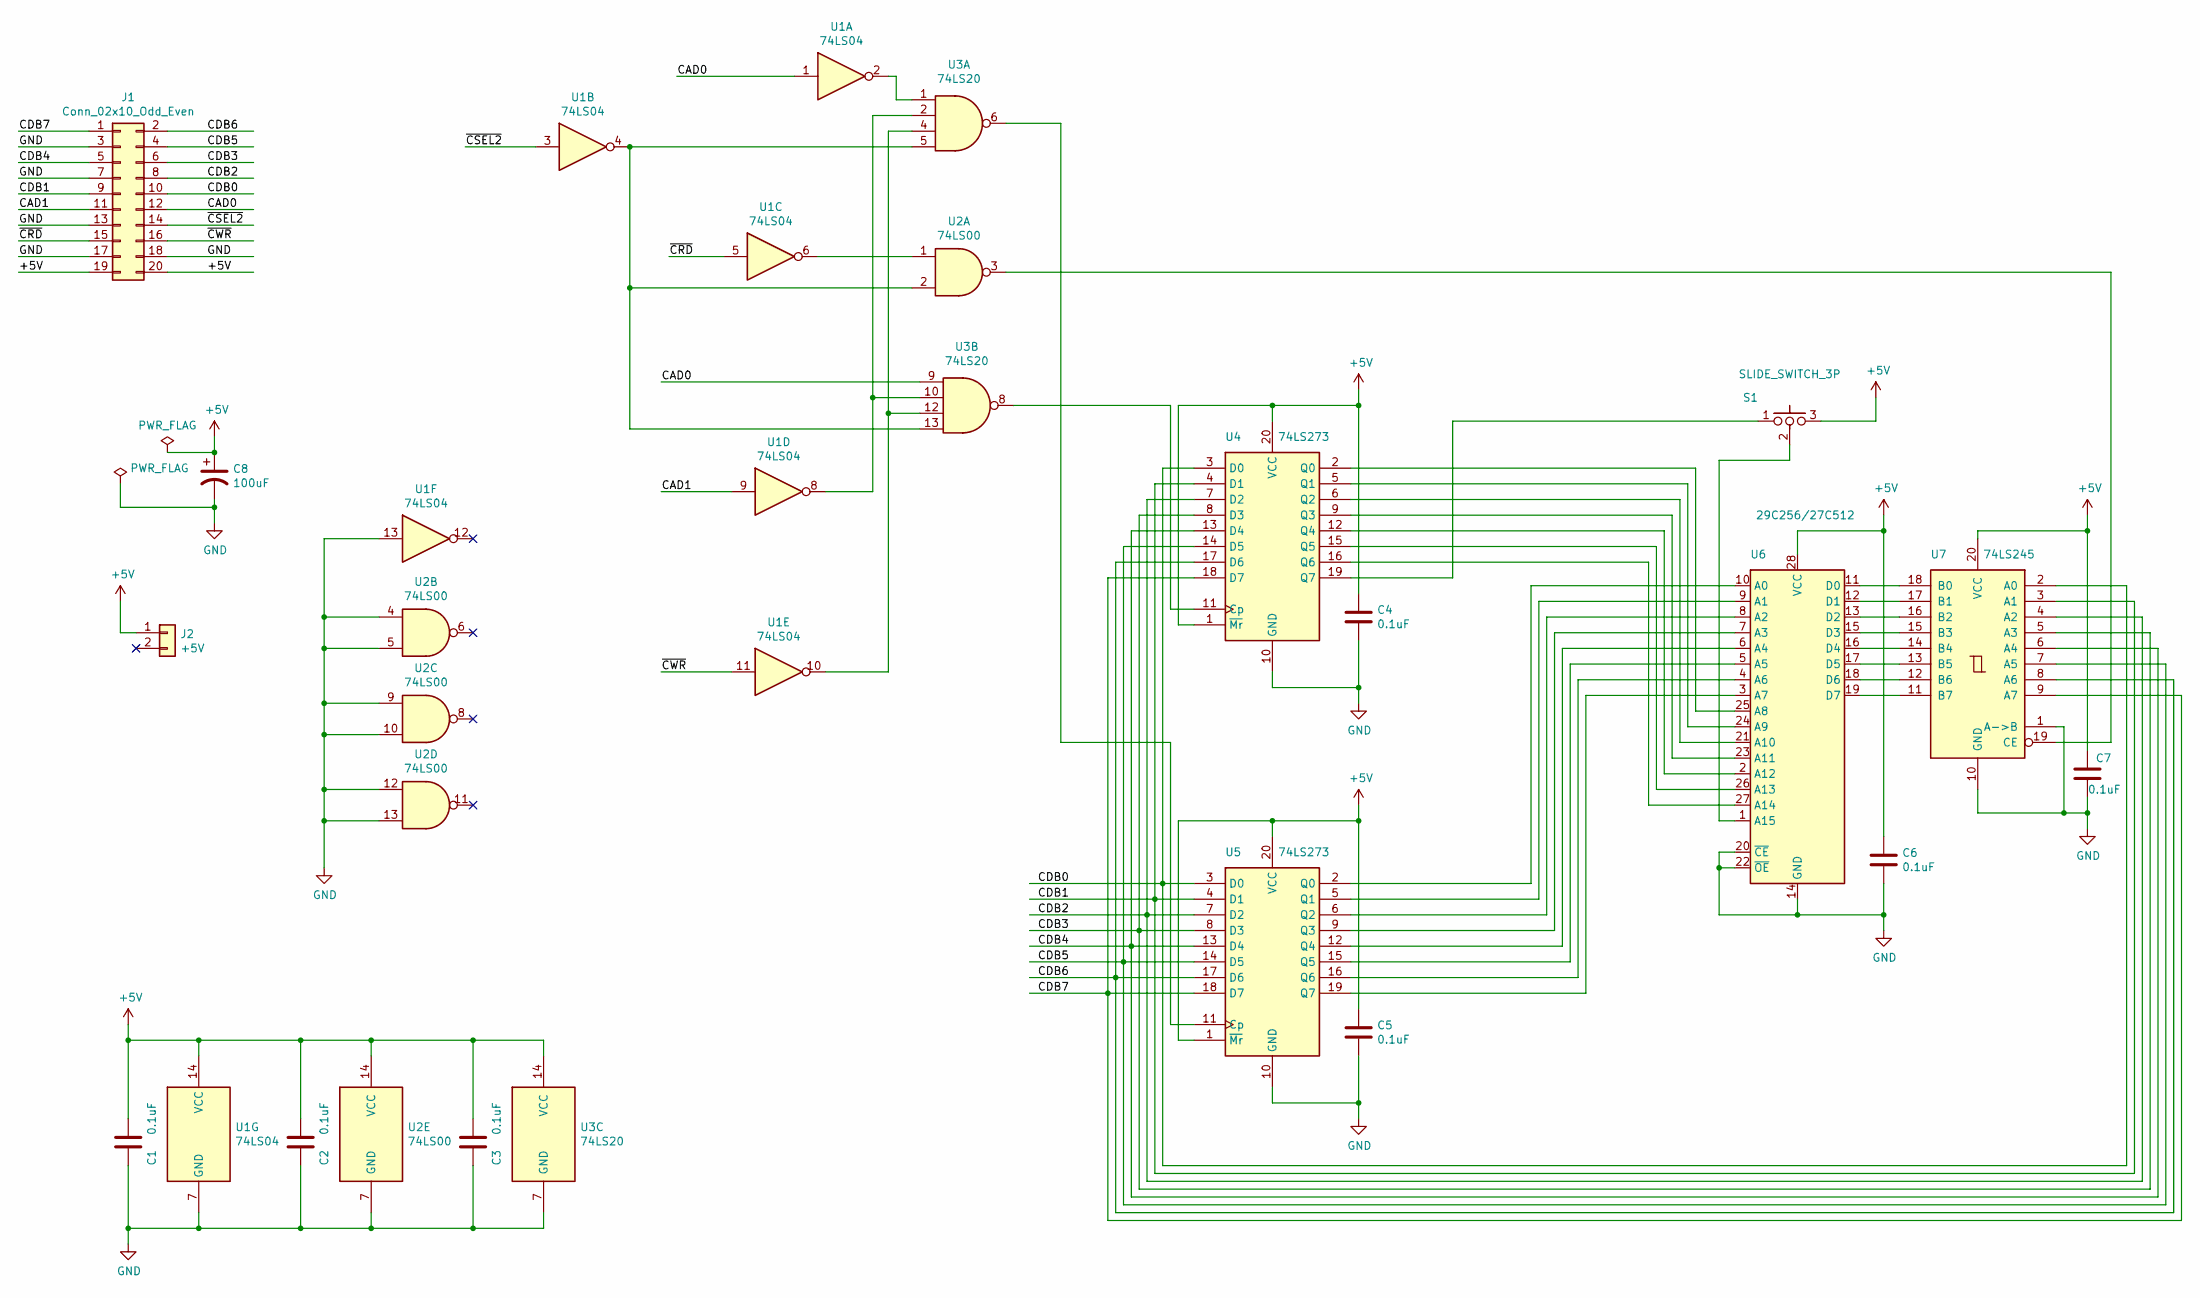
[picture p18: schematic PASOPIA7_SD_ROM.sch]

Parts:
C1, C2, C3, C4, C5, C6, C7: 0.1uF; C_Rect_L4.0mm_W2.5mm_P2.50mm
C8: 100uF; CP_Radial_D5.0mm_P2.50mm
J1: Conn_02x10_Odd_Even; PinHeader_2x10_P2.54mm_Vertical
J2: +5V; PinHeader_1x02_P2.54mm_Horizontal
S1: SLIDE_SWITCH_3P; PinHeader_1x03_P2.54mm_Vertical
U1: 74LS04; DIP-14_W7.62mm_LongPads
U2: 74LS00; DIP-14_W7.62mm_LongPads
U3: 74LS20; DIP-14_W7.62mm_LongPads
U4, U5: 74LS273; DIP-20_W7.62mm_LongPads
U6: 29C256/27C512; DIP-28_W15.24mm_LongPads
U7: 74LS245; DIP-20_W7.62mm_LongPads

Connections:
+5V: C1.2, C2.2, C3.2, C4.1, C5.1, C6.1, C7.1, C8.1, J1.19, J1.20, J2.1, S1.3, U1.14 (VCC), U2.14 (VCC), U3.14 (VCC), U4.1 (~Mr), U4.20 (VCC), U5.1 (~Mr), U5.20 (VCC), U6.28 (VCC), U7.20 (VCC)
/CAD0: J1.12, U1.1, U3.9
/CAD1: J1.11, U1.9
/CDB0: J1.10, U4.3 (D0), U5.3 (D0), U7.2 (A0)
/CDB1: J1.9, U4.4 (D1), U5.4 (D1), U7.3 (A1)
/CDB2: J1.8, U4.7 (D2), U5.7 (D2), U7.4 (A2)
/CDB3: J1.6, U4.8 (D3), U5.8 (D3), U7.5 (A3)
/CDB4: J1.5, U4.13 (D4), U5.13 (D4), U7.6 (A4)
/CDB5: J1.4, U4.14 (D5), U5.14 (D5), U7.7 (A5)
/CDB6: J1.2, U4.17 (D6), U5.17 (D6), U7.8 (A6)
/CDB7: J1.1, U4.18 (D7), U5.18 (D7), U7.9 (A7)
/~CRD: J1.15, U1.5
/~CSEL2: J1.14, U1.3
/~CWR: J1.16, U1.11
GND: C1.1, C2.1, C3.1, C4.2, C5.2, C6.2, C7.2, C8.2, J1.3, J1.7, J1.13, J1.17, J1.18, U1.7 (GND), U1.13, U2.4, U2.5, U2.7 (GND), U2.9, U2.10, U2.12, U2.13, U3.7 (GND), U4.10 (GND), U5.10 (GND), U6.14 (GND), U6.20 (~CE), U6.22 (~OE), U7.1 (A->B), U7.10 (GND)
unnamed: S1.1, U4.19 (Q7)
unnamed: S1.2, U6.1 (A15)
unnamed: U1.2, U3.1
unnamed: U1.4, U2.2, U3.5, U3.13
unnamed: U1.6, U2.1
unnamed: U1.8, U3.2, U3.10
unnamed: U1.10, U3.4, U3.12
unnamed: U2.3, U7.19 (CE)
unnamed: U3.6, U5.11 (Cp)
unnamed: U3.8, U4.11 (Cp)
unnamed: U4.2 (Q0), U6.25 (A8)
unnamed: U4.5 (Q1), U6.24 (A9)
unnamed: U4.6 (Q2), U6.21 (A10)
unnamed: U4.9 (Q3), U6.23 (A11)
unnamed: U4.12 (Q4), U6.2 (A12)
unnamed: U4.15 (Q5), U6.26 (A13)
unnamed: U4.16 (Q6), U6.27 (A14)
unnamed: U5.2 (Q0), U6.10 (A0)
unnamed: U5.5 (Q1), U6.9 (A1)
unnamed: U5.6 (Q2), U6.8 (A2)
unnamed: U5.9 (Q3), U6.7 (A3)
unnamed: U5.12 (Q4), U6.6 (A4)
unnamed: U5.15 (Q5), U6.5 (A5)
unnamed: U5.16 (Q6), U6.4 (A6)
unnamed: U5.19 (Q7), U6.3 (A7)
unnamed: U6.11 (D0), U7.18 (B0)
unnamed: U6.12 (D1), U7.17 (B1)
unnamed: U6.13 (D2), U7.16 (B2)
unnamed: U6.15 (D3), U7.15 (B3)
unnamed: U6.16 (D4), U7.14 (B4)
unnamed: U6.17 (D5), U7.13 (B5)
unnamed: U6.18 (D6), U7.12 (B6)
unnamed: U6.19 (D7), U7.11 (B7)

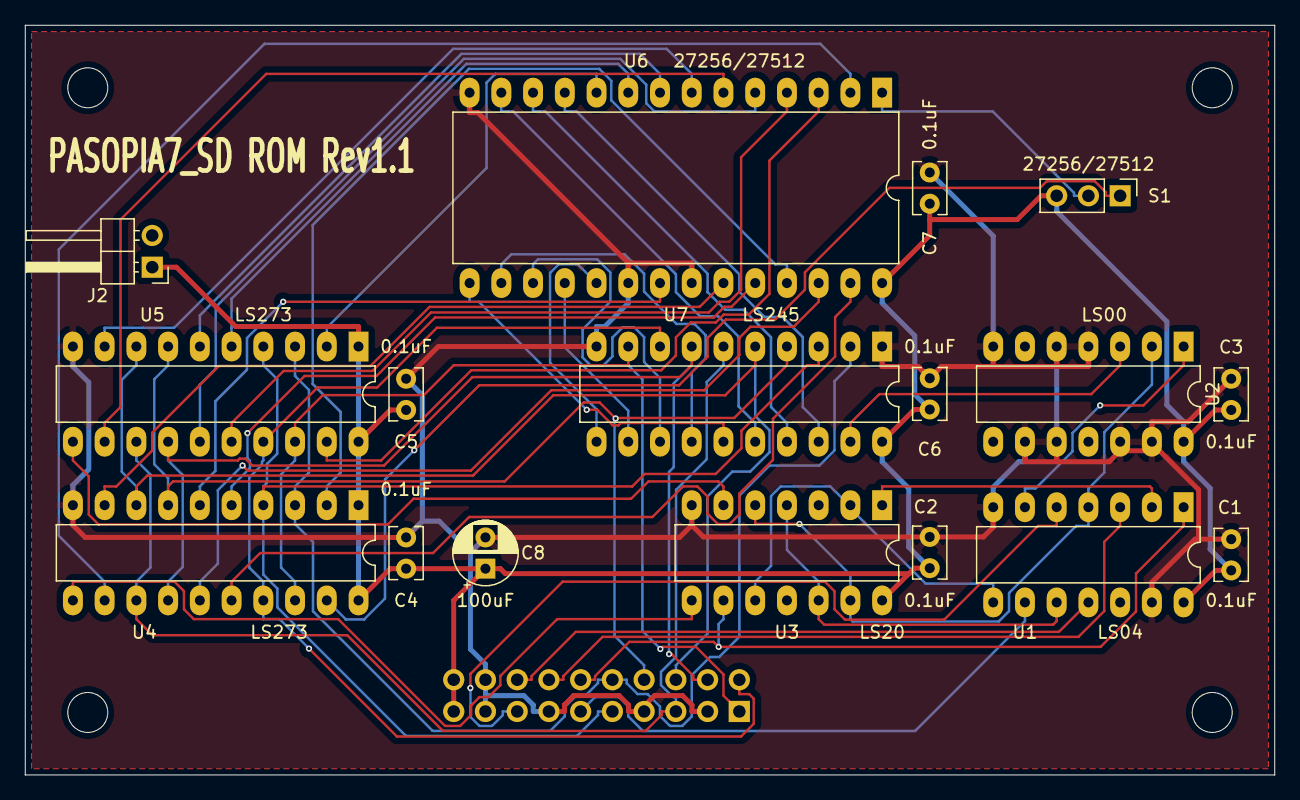
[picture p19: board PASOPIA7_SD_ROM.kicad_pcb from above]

Board: 2 copper layers, 100.0 x 60.0 mm, 22 parts (1 on the bottom side), 48 nets.

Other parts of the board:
MH1, MH2, MH3, MH4: MountingHole_3.2mm_M3

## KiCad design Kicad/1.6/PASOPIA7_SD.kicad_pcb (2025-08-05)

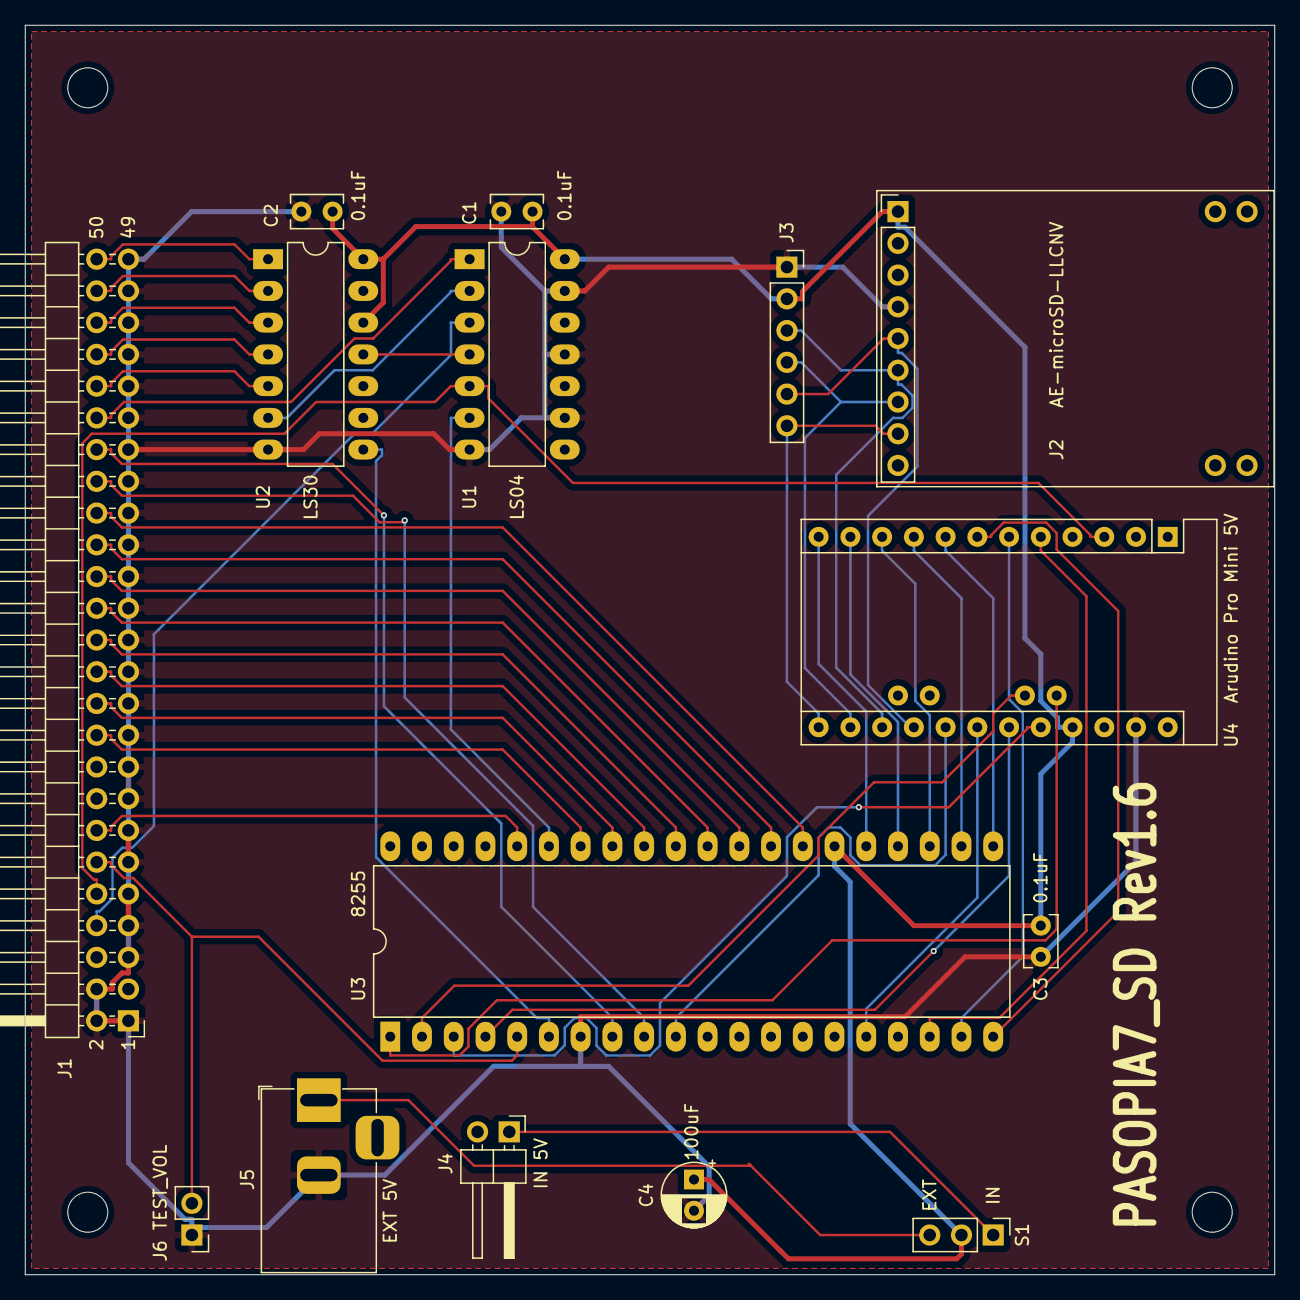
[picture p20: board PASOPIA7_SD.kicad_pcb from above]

Board: 2 copper layers, 100.0 x 100.0 mm, 19 parts (0 on the bottom side), 46 nets.

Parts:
C1, C2, C3: 0.1uF; C_Rect_L4.0mm_W2.5mm_P2.50mm
C4: 100uF; CP_Radial_D5.0mm_P2.50mm
J1: PASOPIA7 BUS; PinHeader_2x25_P2.54mm_Horizontal
J2: Micro_SD_Card_Kit; AE-microSD-LLCNV
J3: MicroSD Card Adapter; PinSocket_1x06_P2.54mm_Vertical
J4: IN 5V; PinHeader_1x02_P2.54mm_Horizontal
J5: EXT 5V; BarrelJack_Horizontal
J6: TEST_VOL; PinHeader_1x02_P2.54mm_Vertical
MH1, MH2, MH3, MH4: MountingHole_3.2mm_M3
S1: IN / OUT; PinHeader_1x03_P2.54mm_Vertical
U1: 74LS04; DIP-14_W7.62mm_LongPads
U2: 74LS30; DIP-14_W7.62mm_LongPads
U3: 8255; DIP-40_W15.24mm_LongPads
U4: Arduino_Pro_Mini_5V; Arduino_Pro_Mini

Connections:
+5V: C1.2, C2.2, C3.1, C4.1, J2.1, J3.2, S1.2, U1.14, U2.12, U2.14, U3.26, U4.21
/CS: J2.8, J3.6, U4.13
/CZAD0: J1.36, U3.9
/CZAD1: J1.38, U3.8
/CZAD2: J1.40, U1.1
/CZAD3: J1.42, U2.5
/CZAD4: J1.44, U2.4
/CZAD5: J1.46, U2.3
/CZAD6: J1.48, U2.2
/CZAD7: J1.50, U2.1
/CZDB0: J1.20, U3.34
/CZDB1: J1.22, U3.33
/CZDB2: J1.24, U3.32
/CZDB3: J1.26, U3.31
/CZDB4: J1.28, U3.30
/CZDB5: J1.30, U3.29
/CZDB6: J1.32, U3.28
/CZDB7: J1.34, U3.27
/CZIORQ: J1.8, U1.3
/CZRD: J1.12, J6.2, U3.5
/CZRST: J1.10, U1.5, U4.3
/CZWR: J1.14, U3.36
/MISO: J2.6, J3.3, U4.15
/MOSI: J2.7, J3.4, U4.14
/SCK: J2.5, J3.5, U4.16
GND: C1.1, C2.1, C3.2, C4.2, J1.1, J1.2, J1.4, J1.5, J1.7, J1.9, J1.11, J1.13, J1.15, J1.17, J1.19, J1.21, J1.23, J1.25, J1.27, J1.29, J1.31, J1.33, J1.35, J1.37, J1.39, J1.41, J1.43, J1.45, J1.47, J1.49, J2.4, J3.1, J5.2, J6.1, U1.7, U1.9, U1.11, U1.13, U2.7, U3.7, U4.23
unnamed: J4.1, S1.1
unnamed: J5.1, S1.3
unnamed: U1.2, U2.6
unnamed: U1.4, U2.11
unnamed: U1.6, U3.35
unnamed: U2.8, U3.6
unnamed: U3.1, U4.A5
unnamed: U3.2, U4.A4
unnamed: U3.3, U4.20
unnamed: U3.4, U4.19
unnamed: U3.10, U4.17
unnamed: U3.16, U4.18
unnamed: U3.18, U4.5
unnamed: U3.19, U4.6
unnamed: U3.20, U4.7
unnamed: U3.21, U4.8
unnamed: U3.22, U4.9
unnamed: U3.23, U4.10
unnamed: U3.24, U4.11
unnamed: U3.25, U4.12

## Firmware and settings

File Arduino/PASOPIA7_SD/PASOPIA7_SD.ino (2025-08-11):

#include "SdFat.h"
#include <SPI.h>
SdFat SD;
char m_name[40];
char f_name[40];
char c_name[40];
char sdir[10][40];
File file_r,file_w;
byte f_length2,f_length1;
unsigned long r_count=0;
unsigned int f_length=0;

#define CABLESELECTPIN  (10)
#define CHKPIN          (15)
#define PB0PIN          (2)
#define PB1PIN          (3)
#define PB2PIN          (4)
#define PB3PIN          (5)
#define PB4PIN          (6)
#define PB5PIN          (7)
#define PB6PIN          (8)
#define PB7PIN          (9)
#define FLGPIN          (14)
#define PA0PIN          (16)
#define PA1PIN          (17)
#define PA2PIN          (18)
#define PA3PIN          (19)
// ファイル名は、ロングファイルネーム形式対応
boolean eflg;

void sdinit(void){
  // SD初期化
  if( !SD.begin(CABLESELECTPIN,8) )
  {
////    Serial.println("Failed : SD.begin");
    eflg = true;
  } else {
////    Serial.println("OK : SD.begin");
    eflg = false;
  }
////    Serial.println("START");
}

void setup(){
////  Serial.begin(9600);
// CS=pin10
// pin10 output

  pinMode(CABLESELECTPIN,OUTPUT);
  pinMode( CHKPIN,INPUT);  //CHK
  pinMode( PB0PIN,OUTPUT); //送信データ
  pinMode( PB1PIN,OUTPUT); //送信データ
  pinMode( PB2PIN,OUTPUT); //送信データ
  pinMode( PB3PIN,OUTPUT); //送信データ
  pinMode( PB4PIN,OUTPUT); //送信データ
  pinMode( PB5PIN,OUTPUT); //送信データ
  pinMode( PB6PIN,OUTPUT); //送信データ
  pinMode( PB7PIN,OUTPUT); //送信データ
  pinMode( FLGPIN,OUTPUT); //FLG

  pinMode( PA0PIN,INPUT_PULLUP); //受信データ
  pinMode( PA1PIN,INPUT_PULLUP); //受信データ
  pinMode( PA2PIN,INPUT_PULLUP); //受信データ
  pinMode( PA3PIN,INPUT_PULLUP); //受信データ

  digitalWrite(PB0PIN,LOW);
  digitalWrite(PB1PIN,LOW);
  digitalWrite(PB2PIN,LOW);
  digitalWrite(PB3PIN,LOW);
  digitalWrite(PB4PIN,LOW);
  digitalWrite(PB5PIN,LOW);
  digitalWrite(PB6PIN,LOW);
  digitalWrite(PB7PIN,LOW);
  digitalWrite(FLGPIN,LOW);

  sdinit();
}

//4BIT受信
byte rcv4bit(void){
//HIGHになるまでループ
  while(digitalRead(CHKPIN) != HIGH){
  }
//受信
  byte j_data = digitalRead(PA0PIN)+digitalRead(PA1PIN)*2+digitalRead(PA2PIN)*4+digitalRead(PA3PIN)*8;
//FLGをセット
  digitalWrite(FLGPIN,HIGH);
//LOWになるまでループ
  while(digitalRead(CHKPIN) == HIGH){
  }
//FLGをリセット
  digitalWrite(FLGPIN,LOW);
  return(j_data);
}

//1BYTE受信
byte rcv1byte(void){
  byte i_data = 0;
  i_data=rcv4bit()*16;
  i_data=i_data+rcv4bit();
  return(i_data);
}

//1BYTE送信
void snd1byte(byte i_data){
//下位ビットから8ビット分をセット
  digitalWrite(PB0PIN,(i_data)&0x01);
  digitalWrite(PB1PIN,(i_data>>1)&0x01);
  digitalWrite(PB2PIN,(i_data>>2)&0x01);
  digitalWrite(PB3PIN,(i_data>>3)&0x01);
  digitalWrite(PB4PIN,(i_data>>4)&0x01);
  digitalWrite(PB5PIN,(i_data>>5)&0x01);
  digitalWrite(PB6PIN,(i_data>>6)&0x01);
  digitalWrite(PB7PIN,(i_data>>7)&0x01);
  digitalWrite(FLGPIN,HIGH);
//HIGHになるまでループ
  while(digitalRead(CHKPIN) != HIGH){
  }
  digitalWrite(FLGPIN,LOW);
//LOWになるまでループ
  while(digitalRead(CHKPIN) == HIGH){
  }
}

//ファイル名の最後が「.bin」なら0,「.bas」なら1,どちらでもなければ0xFF
byte extchk(char *f_name){
  unsigned int lp1=0;
  byte r_data = 0xFF;
  while (f_name[lp1] != 0x00){
//    m_name[lp1] = f_name[lp1];
    lp1++;
  }
  if (f_name[lp1-4]=='.' &&
    ( f_name[lp1-3]=='B' ||
      f_name[lp1-3]=='b' ) &&
    ( f_name[lp1-2]=='I' ||
      f_name[lp1-2]=='i' ) &&
    ( f_name[lp1-1]=='N' ||
      f_name[lp1-1]=='n' ) ){
         r_data = 0;
  }
  if (f_name[lp1-4]=='.' &&
    ( f_name[lp1-3]=='B' ||
      f_name[lp1-3]=='b' ) &&
    ( f_name[lp1-2]=='A' ||
      f_name[lp1-2]=='a' ) &&
    ( f_name[lp1-1]=='S' ||
      f_name[lp1-1]=='s' ) ){
         r_data = 1;
  }
  if (f_name[lp1-4]=='.' &&
    ( f_name[lp1-3]=='F' ||
      f_name[lp1-3]=='f' ) &&
    ( f_name[lp1-2]=='P' ||
      f_name[lp1-2]=='p' ) &&
    ( f_name[lp1-1]=='T' ||
      f_name[lp1-1]=='t' ) ){
         r_data = 2;
  }
  return(r_data);
}

//ファイル名の最後が「.bin」でなければ付加
void addbin(char *f_name,char *m_name){
  unsigned int lp1=0;
  while (f_name[lp1] != 0x00){
    m_name[lp1] = f_name[lp1];
////  Serial.println(f_name[lp1],HEX);
    lp1++;
  }
  if (f_name[lp1-4]!='.' ||
    ( f_name[lp1-3]!='B' &&
      f_name[lp1-3]!='b' ) ||
    ( f_name[lp1-2]!='I' &&
      f_name[lp1-2]!='i' ) ||
    ( f_name[lp1-1]!='N' &&
      f_name[lp1-1]!='n' ) ){
         m_name[lp1++] = '.';
         m_name[lp1++] = 'b';
         m_name[lp1++] = 'i';
         m_name[lp1++] = 'n';
  }
  m_name[lp1] = 0x00;
}

//ファイル名の最後が「.bas」でなければ付加
void addbas(char *f_name,char *m_name){
  unsigned int lp1=0;
  while (f_name[lp1] != 0x00){
    m_name[lp1] = f_name[lp1];
    lp1++;
  }
  if (f_name[lp1-4]!='.' ||
    ( f_name[lp1-3]!='B' &&
      f_name[lp1-3]!='b' ) ||
    ( f_name[lp1-2]!='A' &&
      f_name[lp1-2]!='a' ) ||
    ( f_name[lp1-1]!='S' &&
      f_name[lp1-1]!='s' ) ){
         m_name[lp1++] = '.';
         m_name[lp1++] = 'b';
         m_name[lp1++] = 'a';
         m_name[lp1++] = 's';
  }
  m_name[lp1] = 0x00;
}

//比較文字列取得 32+1文字まで取得、ただしダブルコーテーションは無視する
void receive_name(char *f_name){
char r_data;
  unsigned int lp2 = 0;
  for (unsigned int lp1 = 0;lp1 <= 32;lp1++){
    r_data = rcv1byte();
    if (r_data != 0x22){
      f_name[lp2] = r_data;
      lp2++;
    }
  }
////  Serial.println(f_name);
}

//SDカードから機械語を読込
void fm_load(void){
  int wk1 = 0;
  unsigned int lp1;
//ファイルネーム取得
  receive_name(f_name);
  addbin(f_name,m_name);
////  Serial.println(m_name);
//ファイルが存在しなければERROR
  if (SD.exists(m_name) == true){
//ファイルオープン
    file_r = SD.open( m_name, FILE_READ );
    if( true == file_r ){
//状態コード送信(OK)
        snd1byte(0x00);

//ファイルサイズ取得
          f_length = file_r.size()-4;
          f_length2 = f_length % 256;
          f_length1 = f_length / 256;
          snd1byte(f_length2);
          snd1byte(f_length1);

//          if(rcv1byte()==0x00){
//データ送信
            wk1 = file_r.read();
            snd1byte(wk1);
            wk1 = file_r.read();
            snd1byte(wk1);
            wk1 = file_r.read();
            wk1 = file_r.read();
            if(f_length>0){
              for (lp1 = 1;lp1 <= f_length;lp1++){
                wk1 = file_r.read();
                snd1byte(wk1);
              }
//            }
          }
        file_r.close();
        sdinit();
     } else {
//状態コード送信(ERROR)
      snd1byte(0xFF);
      sdinit();
     }
   } else {
//状態コード送信(FILE NOT FIND ERROR)
    snd1byte(0xF1);
    sdinit();
  }
}

//SDカードからBASICプログラムを読込
void fb_load(void){
  int wk1 = 0;
  unsigned int lp1;
//ファイルネーム取得
  receive_name(f_name);
  addbas(f_name,m_name);
////  Serial.println(m_name);
//ファイルが存在しなければERROR
  if (SD.exists(m_name) == true){
//ファイルオープン
    file_r = SD.open( m_name, FILE_READ );
    if( true == file_r ){
//状態コード送信(OK)
        snd1byte(0x00);

//ファイルサイズ取得
          f_length = file_r.size();
          f_length2 = f_length % 256;
          f_length1 = f_length / 256;
          snd1byte(f_length2);
          snd1byte(f_length1);

          if(rcv1byte()==0x00){
//データ送信
            if(f_length>0){
              for (lp1 = 1;lp1 <= f_length;lp1++){
                wk1 = file_r.read();
                snd1byte(wk1);
              }
            }
          }
        file_r.close();
        sdinit();
     } else {
//状態コード送信(ERROR)
      snd1byte(0xFF);
      sdinit();
     }
   } else {
//状態コード送信(FILE NOT FIND ERROR)
    snd1byte(0xF1);
    sdinit();
  }
}

//SDカードにBASICプログラムを書き込み
void fb_save(void){
  int wk1 = 0;
  unsigned long lp1;
//ファイルネーム取得
  receive_name(f_name);
  addbas(f_name,m_name);
//
//ファイルが存在すればdelete
  if (SD.exists(m_name) == true){
    SD.remove(m_name);
  }
//ファイルオープン
  file_w = SD.open( m_name, FILE_WRITE );
  if( true == file_w ){
//状態コード送信(OK)
    snd1byte(0x00);
      f_length1 = rcv1byte();
      f_length2 = rcv1byte();
      f_length = f_length2*256+f_length1;

      if(f_length>0){
        for (lp1 = 1;lp1 <= f_length;lp1++){
          wk1 = rcv1byte();
          file_w.write(wk1);
        }
      }
    file_w.close();
  } else {
//状態コード送信(ERROR)
    snd1byte(0xF1);
    sdinit();
  }
}

//SDカードに機械語を書き込み
void fm_save(void){
  int wk1 = 0;
  unsigned int lp1,s_adrs,g_adrs;
  byte s_adrs1,s_adrs2,g_adrs1,g_adrs2;
//ファイルネーム取得
  receive_name(f_name);
  addbin(f_name,m_name);
//
//ファイルが存在すればdelete
  if (SD.exists(m_name) == true){
    SD.remove(m_name);
  }
//ファイルオープン
  file_w = SD.open( m_name, FILE_WRITE );
  if( true == file_w ){
//状態コード送信(OK)
    snd1byte(0x00);
      f_length1 = rcv1byte();
      f_length2 = rcv1byte();
      f_length = f_length2*256+f_length1;

      s_adrs1 = rcv1byte();
      s_adrs2 = rcv1byte();
      s_adrs = s_adrs2*256+s_adrs1;

      f_length = f_length-s_adrs+1;
      f_length2 = f_length / 256;
      f_length1 = f_length % 256;
      file_w.write(s_adrs1);
      file_w.write(s_adrs2);
      file_w.write(f_length1);
      file_w.write(f_length2);

      if(f_length>0){
        for (lp1 = 1;lp1 <= f_length;lp1++){
          wk1 = rcv1byte();
          file_w.write(wk1);
        }
      }
    file_w.close();
  } else {
//状態コード送信(ERROR)
    snd1byte(0xF1);
    sdinit();
  }
}

//f_nameとc_nameをc_nameに0x00が出るまで比較
//FILENAME COMPARE
boolean f_match(char *f_name,char *c_name){
  boolean flg1 = true;
  unsigned int lp1 = 0;
  while (lp1 <=32 && c_name[0] != 0x00 && flg1 == true){
    if (upper(f_name[lp1]) != upper(c_name[lp1])){
      flg1 = false;
    }
    lp1++;
    if (c_name[lp1]==0x00){
      break;
    }
  }
  return flg1;
}

//小文字->大文字
char upper(char c){
  if('a' <= c && c <= 'z'){
    c = c - ('a' - 'A');
  }
  return c;
}


// SD-CARDのFILELIST
void dirlist(void){
  byte extflg;
//比較文字列取得 32+1文字まで
  receive_name(c_name);
  File file2 = SD.open( "/" );
  if( file2 == true ){
//状態コード送信(OK)
    snd1byte(0x00);
   File entry =  file2.openNextFile();
    int cntl2 = 0;
    unsigned int br_chk =0;
    int page = 1;
//全件出力の場合には10件出力したところで一時停止、キー入力により継続、打ち切りを選択
    while (br_chk == 0) {
      if(entry){
        entry.getName(f_name,36);
        unsigned int lp1=0;
//一件送信
//比較文字列でファイルネームを先頭から比較して一致するものだけを出力
        if (f_match(f_name,c_name)){
//sdir[]にf_nameを保存
          strcpy(sdir[cntl2],f_name);
          snd1byte(0x30+cntl2);
          snd1byte(0x20);
          while (lp1<=36 && f_name[lp1]!=0x00){
            snd1byte(f_name[lp1]);
            lp1++;
          }
          snd1byte(0x00);
          cntl2++;
        }
      }
// CNTL2 > 表示件数-1
      if (!entry || cntl2 > 9){
//継続・打ち切り選択指示要求
        snd1byte(0xfe);

//選択指示受信(0:継続 B:前ページ 以外:打ち切り)
        br_chk = rcv1byte();
//前ページ処理
        if (br_chk==0x42){
//先頭ファイルへ
          file2.rewindDirectory();
//entry値更新
          entry =  file2.openNextFile();
//もう一度先頭ファイルへ
          file2.rewindDirectory();
          if(page <= 2){
//現在ページが1ページ又は2ページなら1ページ目に戻る処理
            page = 0;
          } else {
//現在ページが3ページ以降なら前々ページまでのファイルを読み飛ばす
            page = page -2;
            cntl2=0;
//page*表示件数
            while(cntl2 < page*10){
                entry =  file2.openNextFile();
                if (f_match(f_name,c_name)){
                  cntl2++;
                }
            }
         }
          br_chk=0;
        }
//1～0までの数字キーが押されたらsdir[]から該当するファイル名を送信
        if(br_chk>=0x30 && br_chk<=0x39){
          file_r = SD.open( sdir[br_chk-0x30], FILE_READ );
          if( file_r == true ){
            extflg = extchk(sdir[br_chk-0x30]);
            unsigned int lp2=0;
            snd1byte(0xFD);
            while (lp2<=36 && sdir[br_chk-0x30][lp2]!=0x00){
              snd1byte(sdir[br_chk-0x30][lp2]);
              lp2++;
            }
            snd1byte(0x00);
            file_r.close();
          }
        }
        page++;
        cntl2 = 0;
      }
//ファイルがまだあるなら次読み込み、なければ打ち切り指示
      if (entry){
        entry =  file2.openNextFile();
      }else{
        br_chk=1;
      }
    }
//処理終了指示
    snd1byte(0xFF);
    snd1byte(0x00);
    snd1byte(extflg);
  }else{
    snd1byte(0xf1);
  }
}

void loop()
{
  digitalWrite(PB2PIN,LOW);
  digitalWrite(PB3PIN,LOW);
  digitalWrite(FLGPIN,LOW);
//コマンド取得待ち
////  Serial.print("cmd:");
  byte cmd = rcv1byte();
////  Serial.println(cmd,HEX);
  if (eflg == false){
    switch(cmd) {
//22hでSDカードからBinary Load
      case 0x22:
//状態コード送信(OK)
////  Serial.println("BINARY LOAD START");
//状態コード送信(OK)
        snd1byte(0x00);
        fm_load();
        break;
//23hでSDカードからBASIC Program Load
      case 0x23:
//状態コード送信(OK)
////  Serial.println("BASIC LOAD START");
//状態コード送信(OK)
        snd1byte(0x00);
        fb_load();
        break;
//24hでSDカードにBinary save
      case 0x24:
//状態コード送信(OK)
////  Serial.println("Binary SAVE START");
//状態コード送信(OK)
        snd1byte(0x00);
        fm_save();
        break;
//25hでSDカードにBASIC Program save
      case 0x25:
//状態コード送信(OK)
////  Serial.println("BASIC Program SAVE START");
//状態コード送信(OK)
        snd1byte(0x00);
        fb_save();
        break;
//21hでSDカードファイル一覧
      case 0x21:
//状態コード送信(OK)
////  Serial.println("SD DIR START");
//状態コード送信(OK)
        snd1byte(0x00);
        sdinit();
        dirlist();
        break;
      default:
//状態コード送信(CMD ERROR)
        snd1byte(0xF4);
    }
  } else {
//状態コード送信(ERROR)
    snd1byte(0xF0);
    sdinit();
  }
}
